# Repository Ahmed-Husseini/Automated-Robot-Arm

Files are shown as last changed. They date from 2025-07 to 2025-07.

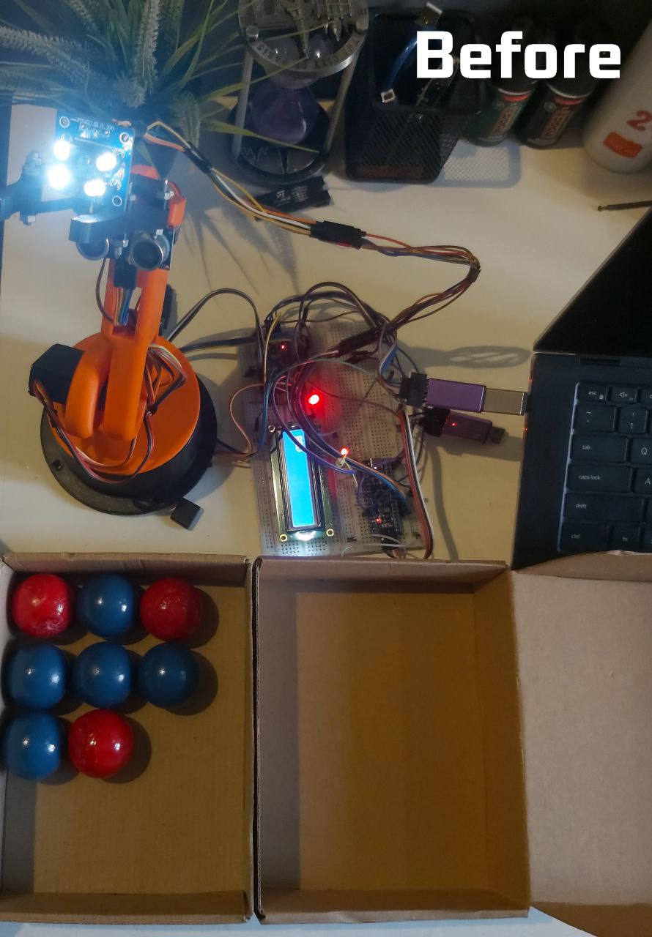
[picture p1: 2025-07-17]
Media/6.jpg

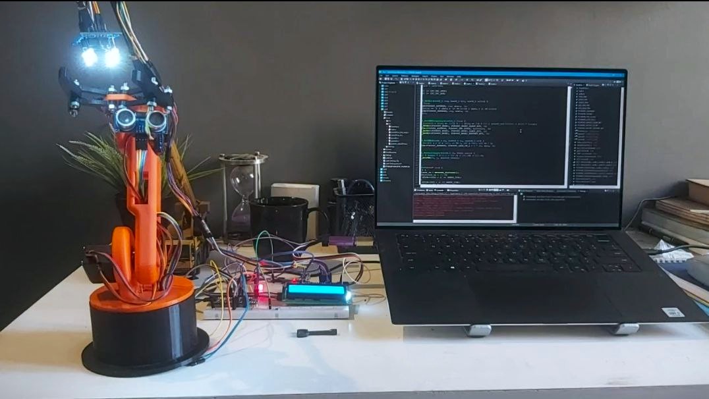
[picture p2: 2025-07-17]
Media/3.jpg

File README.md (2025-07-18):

# Automated-Robot-Arm

An embedded robotic system that classifies and sorts colored objects using a robotic arm controlled by an STM32F103C8T6 microcontroller.

---

## 🎯 Project Overview

The goal of this project is to design, build, and program a robotic arm capable of detecting object color and placing it in the appropriate bin. The robot picks up balls from a central basket, identifies their color using a sensor, and sorts them accordingly.

### 🔄 Operating Logic
1. Arm picks a ball from the central container.
2. A TCS3200 color sensor detects the ball’s color (red or blue).
3. Based on the result:
   - 🔵 Blue → right bin
   - 🔴 Red → left bin
4. The process repeats until the input container is empty.

---

## 🧰 Hardware Components

| Component | Details |
|---|---|
| Microcontroller | STM32F103C8T6 (Blue Pill) |
| Servo Motors | 2× MG966R, 2× SG90 |
| Color Sensor | TCS3200 |
| Ultrasonic Sensor  | HC-SR04 |
| Gyroscope | MPU6050 |
| I2C Servo Driver | PCA9685 |
| LCD (Optional) | I2C 16x2 LCD Display |

---

## 🧠 Software Overview

- **FreeRTOS** used for task scheduling.
- **Register-level programming** (bare-metal) without HAL.
- Key modules:
  - Distance measurement using ultrasonic sensor.
  - Color detection task via TCS3200.
  - Servo control using PCA9685 I2C driver.
- Implemented in C with `CMSIS` and STM32 low-level access.

---

## 📐 Control Design

- DC motor and potentiometer were separated from prebuilt servo loop.
- System modeled and linearized with MATLAB:
  - Moment of Inertia: 0.01 kg·m²
  - Transfer function derived and simulated.
- PID controller designed using MATLAB:
  ```math
  C(s) = 50 + 2s + 100/s

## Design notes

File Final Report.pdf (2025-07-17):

Project Final Report | Mechatronics Engineering MCTR601
Spring 2025

# German University in Cairo

# Mechatronics Engineering (MCTR601)

# Object Classifying Robotic Arm

Name | ID | Lab Number
Ahmed Husseini | 58-21270 | T38
Mohamed Yaser | 58-21125 | T35
Mohamed Mohsen | 58-1653 | T36

## Table of Contents

## 1. Project Description

- Generally explain your project idea and objectives and applications.
- Include a concise overview of what the device does and how it works.
- Mention the main actuators and sensors of the system
- A functional diagram showing all major components and their connections.
- Be sure to label key components in your figures (with concise text and arrows).
Part number | Name
1 Base
2 Arm
3 Gripplers
4 Servo Motors

Overview:
This project involves designing and implementing a simple robotic arm capable of classifying and sorting objects based on their color. The robot picks up randomly placed balls from a central basket and places them into designated places based on their color.

Working Principle:
1. The robotic arm picks up a ball from the central basket.
2. A color detection sensor determines whether the ball is blue or red.
3. Based on the detected color, the arm moves and places the ball into the corresponding basket: Blue ball → Right basket
Red ball → Left basket
4. The process repeats for each ball until the central basket is empty.

Applications:
- Industry and Automation: This project simulates basic industrial product sorting operations in factories.
- Medical Field: Can be used to classify medicines or blood samples in hospitals or pharmacies.
- AI & Machine Learning Integration: Can be expanded by integrating machine learning for improved object recognition.

Actuators: 2x Servo Motors + 2x Micro Servo Motors
Sensors: Ultrasonic (HC-SR04) + Color Sensor (TCS3200) + Gyro (MPU6050) Modules: Servo I2C Driver (PCA9685) + I2C LCD Screen

## Gripplers

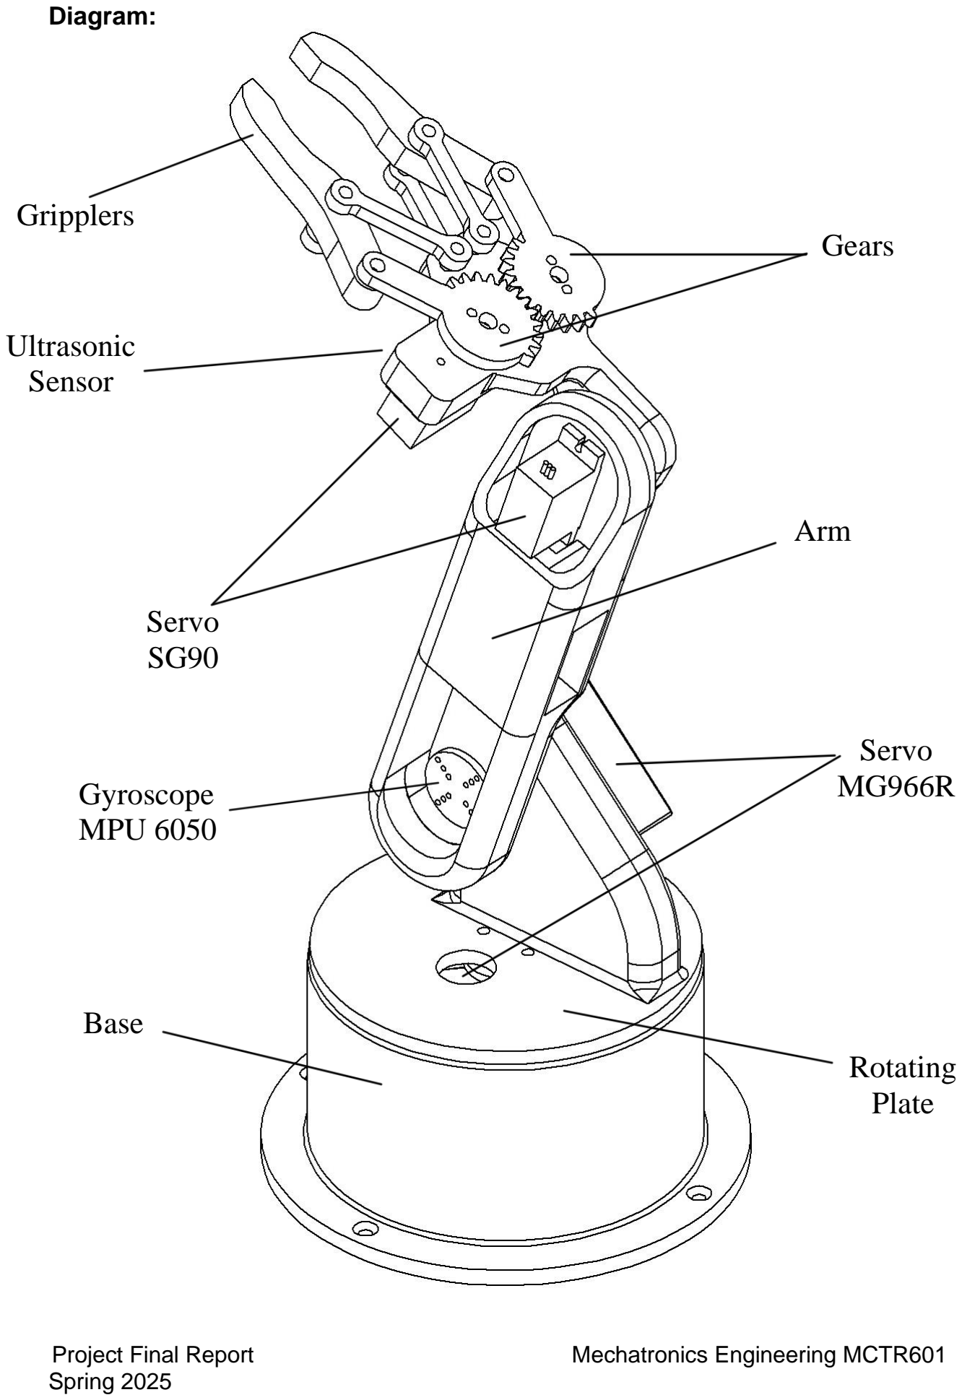
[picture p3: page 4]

Diagram:

## Base

## Arm

## Gears

## Servo MG966R

## Servo

SG90

## Rotating Plate

## Ultrasonic Sensor

## Gyroscope MPU 6050

## 2. Methodology

## 2.1 Mechanical design

Include a detailed description of the system’s mechanical and electromechanical

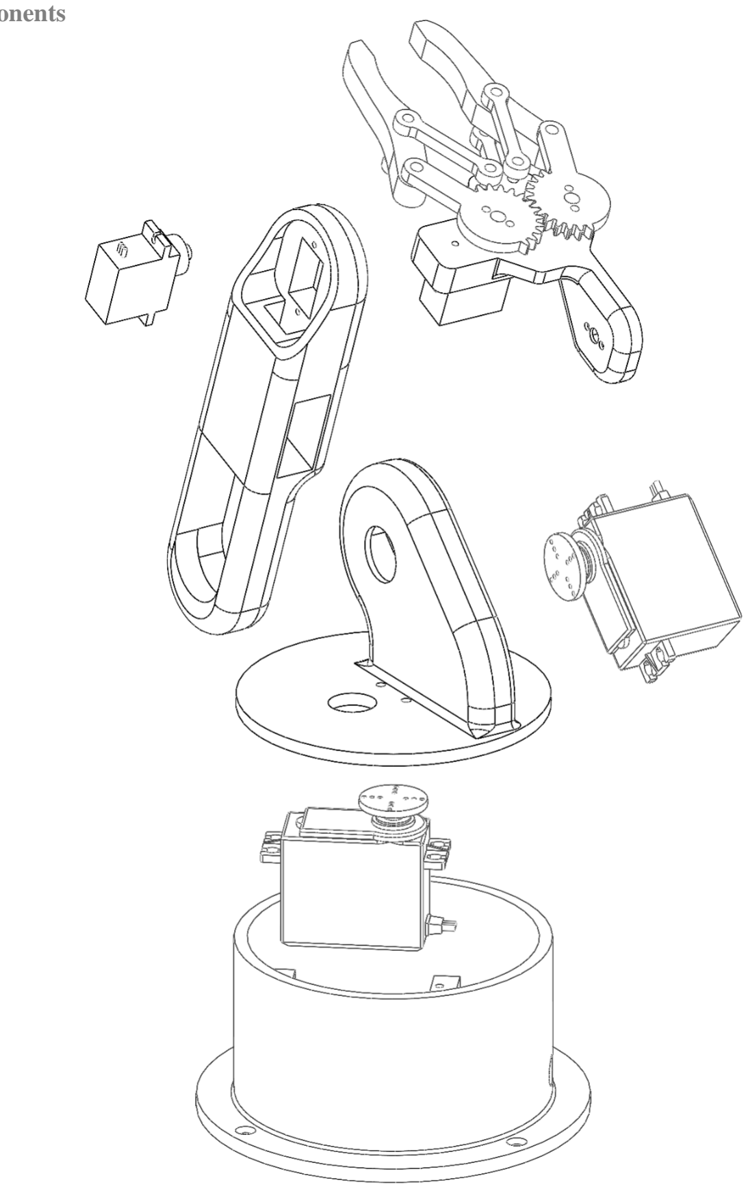
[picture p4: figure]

components

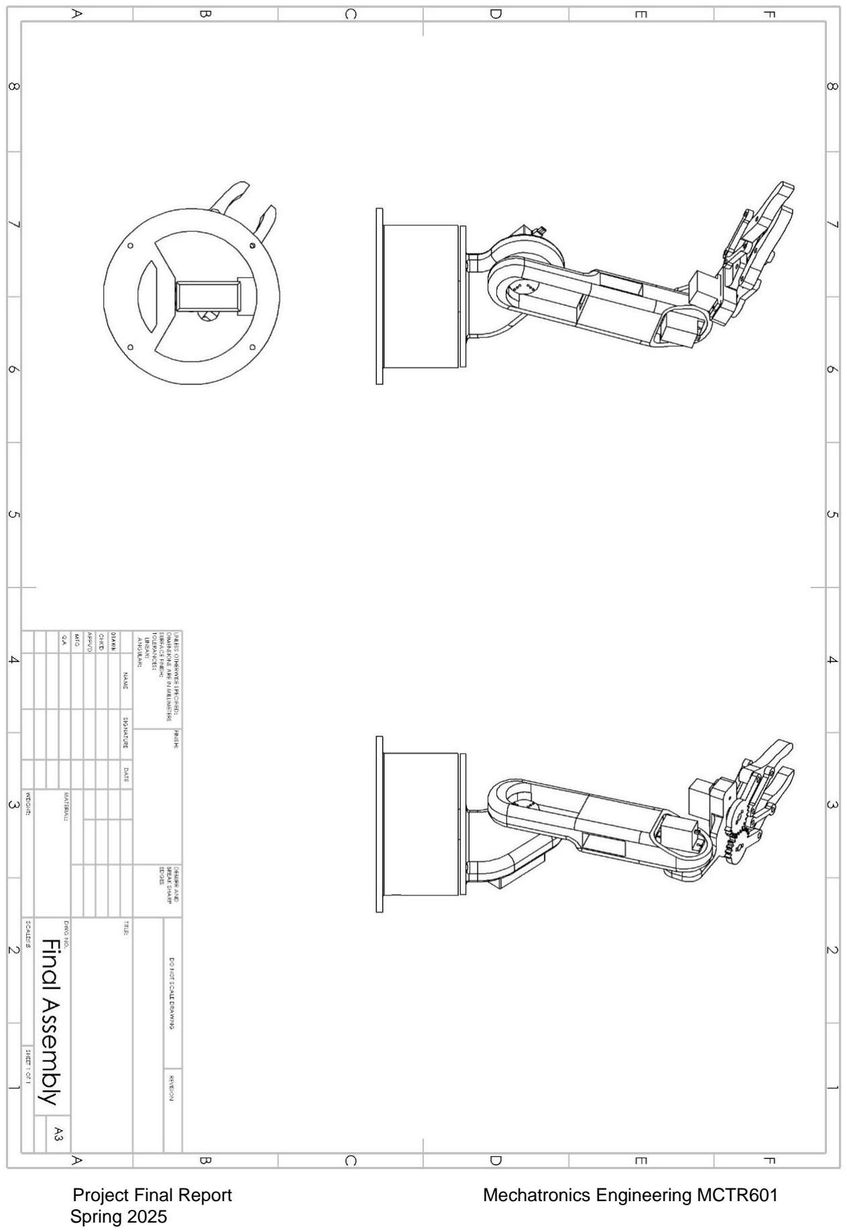
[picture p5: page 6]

## 2.2 Electrical design

Include schematics for the electrical systems showing all connections

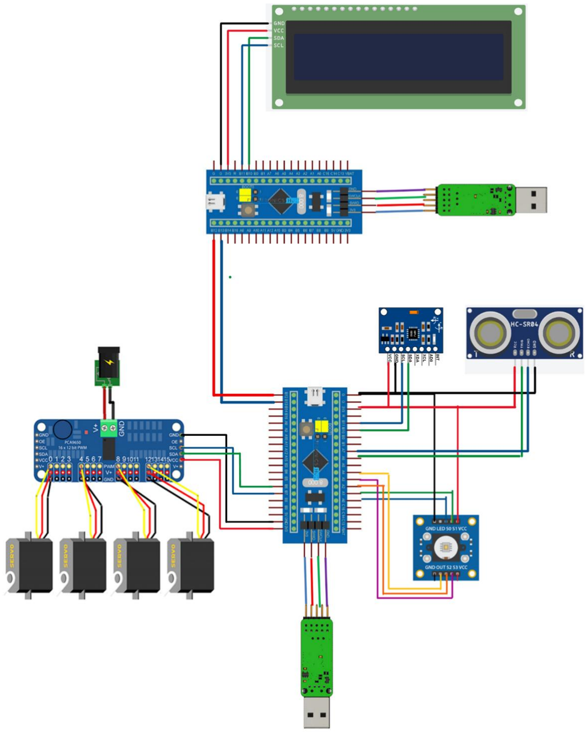
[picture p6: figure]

Control

### 2.3.1. Modeling

This section should show the
- Derivation and linearization of the governing equations
- Derivation of the Transfer function model of the system
- Block Diagram representation

The controlled variable in this project is the motor’s angular position. And since Servo motors already come with a closed-loop control, we hacked it and used the DC motor and the potentiometer individually.

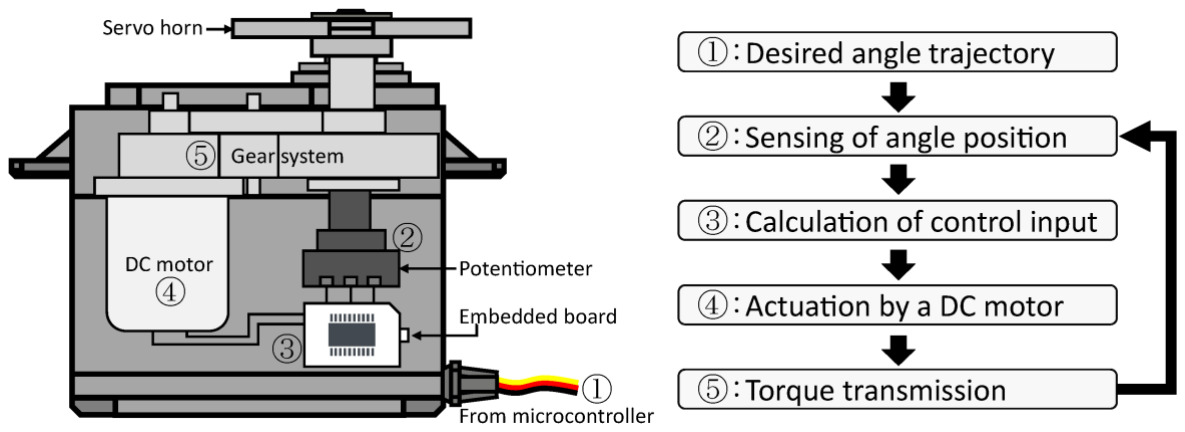
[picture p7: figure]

After simulating the mechanical model of the arm Solidworks, we found that:

### Moment of Inertia (J) = 0.01 kg. m² Damping Coefficient (b) = 0.001 N. m. s

And, from the motor’s datasheet:

### Motor Constant (K) = 0.05 N. m/A Armature Resistance (R) = 2 Ω Armature Inductance (L) = 0.005 H

a) The mathematical model of the DC motor system:

### vi − iR − L

di
dt − Keθ̇m = 0 | (1)
Jmθ̈m = T − Bθ̇m | ⇒ | Jmθ̈m + Bθ̇m = KTi | (2)

### JLθ̈=

1
n
T | ⇒ | JLθ̈=
| | 1 n
| | KTi | (3)

b) Obtaining transfer function:

Using Laplace Transform:

### Eq1: Vi

### (s) − RI(s) − LsI(s) − KesΘm(s) = 0

Vi

(s) = (R + Ls) I(s) + KesΘm(s) | (1)

### Eq2: Jms

### 2Θm(s) + BsΘm(s) = KTI(s)

### Θm(s) =

KT

### Jms

2 + Bs I(s) | (2)

### Eq3: JLs

2Θ(s) −

1
n

### KTI(s) = 0

I(s) =

### nJLs

2
KT
Θ(s) | (3)

from (2) and (3) we get : Θm(s) =

KT
Jms

2+Bs

×

nJLs

2

KT

Θ(s) =

nJLs

2

Jms

2+Bs

Θ(s) | (4)

substituting with (3) and (4) in (1) :

Vi

### (s) = (R + Ls)

### nJLs

2
KT

### Θ(s) + Kes

### nJLs

2

### Jms

### 2 + Bs Θ(s)

Vi

(s) = (

### RnJLs

### 2 + LnJLs

3
KT

+

### KenJLs

3

### Jms

### 2 + Bs)Θ(s)

Vi

(s) =

### nJLs((Jms + B)(Ls + R) + KTKe) JmKT

Θ(s)

Θ(s)
Vi

(s)

=

Jm

### nJL

KT

### s((Jms + B)(Ls + R) + KTKe)

### Transfer Function =

0. 01
10
0. 05

### s((0. 01 s + 0. 001)(0. 005 s + 2) + 0. 05)

c) Simulink Block diagram

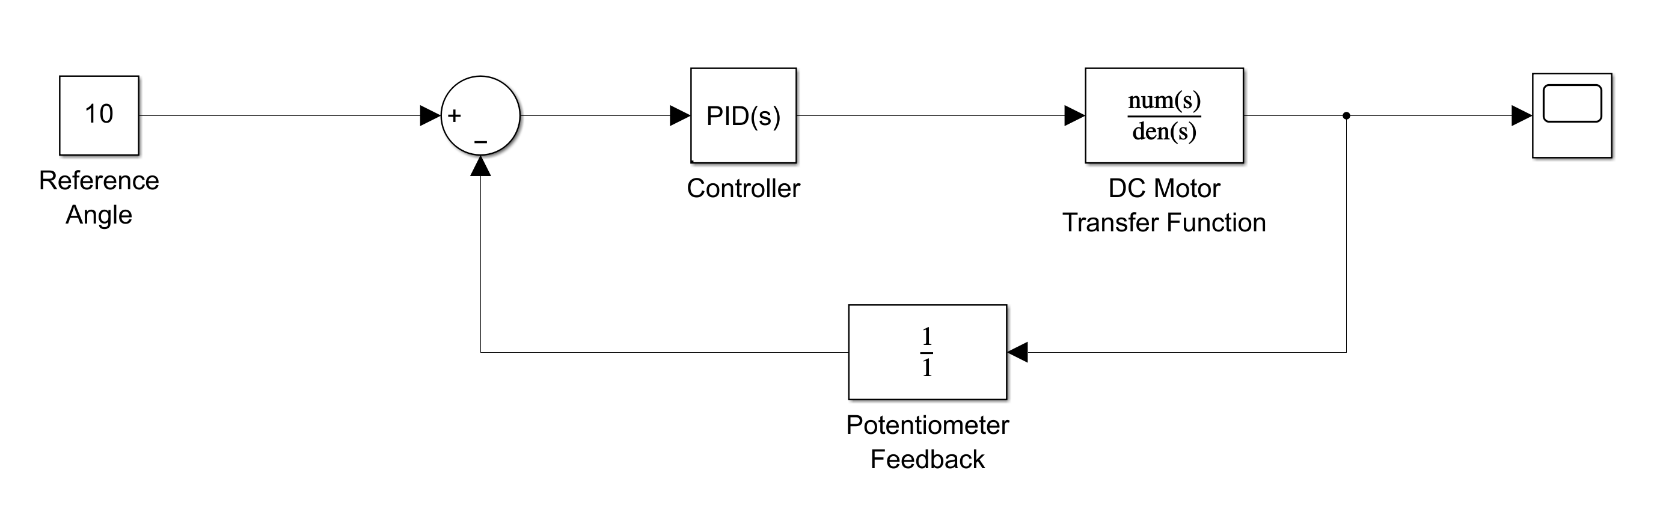
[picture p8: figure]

### 2.3.2. Analysis

- Solve equations and get the open loop response

Step response h(t) = L

−1

{H(s) ∗

1
s

}

H(s) =

### JmKT nJL

1

### s((Jms + B)(Ls + R) + KTKe)

∗

1
s

H(s) =

0.01
10

0.05
s

2((0.01 s + 0.001)(0.005 s + 2) + 0.05)

H(s) =

0.0005
s

2(0.005 s

2 + 2.0005 s + 0.25)

H(s) =

6.188 × 10⁻⁵
s

+

6.188 × 10⁻⁵
s + 3.125 +

6.188 × 10⁻⁵
s + 1374.38

## ℎ(t) = 6.188 × 10⁻⁵ − 6.188 × 10⁻⁵e

## −3.125t − 6.188 × 10⁻⁵e

−1374.38t

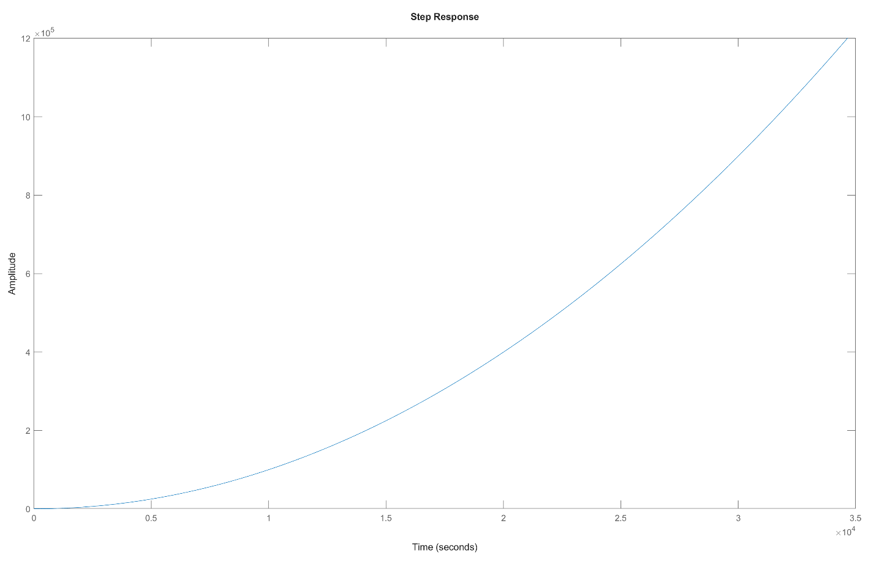
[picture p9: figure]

### 2.3.3. Controller Design

- Show the controller design steps
- Clearly show the control law
- Show the closed loop simulations

Hint: You may use MATLAB’s SISO tool for the simulations in the analysis and design stages

Step 1: Define the Plant in MATLAB
Step 2: Analyze Open-Loop System

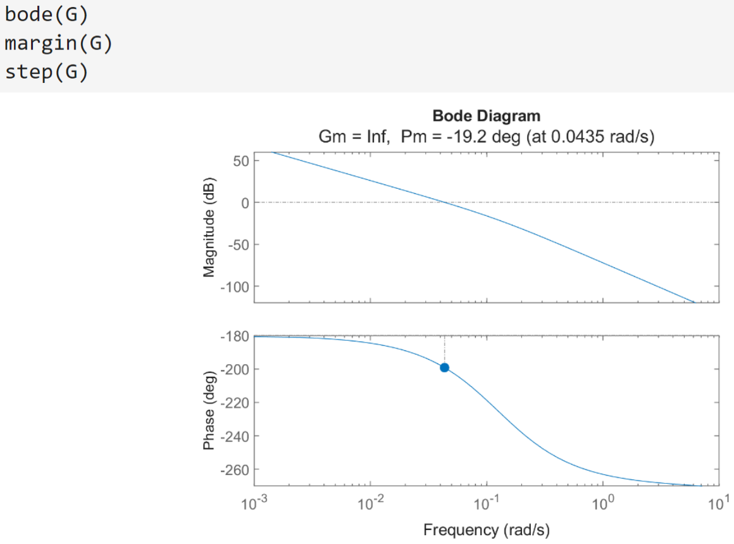
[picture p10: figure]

Step 3: Design PID Controller Using pidtune Function

### C = Kp + Kds +

Ki
s

= 50 + 2 s +

100
s

=

50 s + 2 s

2 + 100
s

Step 4: Form the Closed-Loop System
Step 5: Analyze Closed-Loop Response

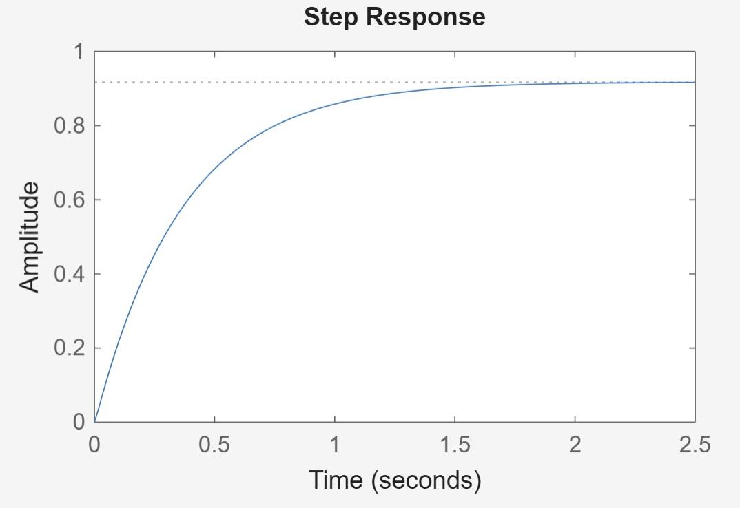
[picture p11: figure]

## 2.3 Programming

Include the used codes and a concise software flowchart

#include "stm32f103xb.h"

#include "FreeRTOS.h"

#include "task.h"

#include <stdio.h>

// ==== PIN DEFINITIONS ====

// Ultrasonic

#define TRIG_PIN | 6 | // PA6

#define ECHO_PIN | 7 | // PA7

#define DEBUG_PIN | 14 // PB14

// Color sensor

#define LED_RED_PIN 12 // PB12 #define LED_BLUE_PIN 13 // PB13

// PCA9685

#define PCA9685_ADDRESS | 0x80

#define PCA9685_MODE1 | 0x00

#define PCA9685_PRE_SCALE | 0xFE

#define PCA9685_LED0_ON_L | 0x06

#define PCA9685_MODE1_SLEEP_BIT 4 #define PCA9685_MODE1_AI_BIT 5 #define PCA9685_MODE1_RESTART_BIT 7

// ==== GLOBAL VARIABLES ====

volatile float distance_cm = 0;
volatile uint16_t capture1 = 0, capture2 = 0; volatile uint8_t captured = 0;

// ==== UTILS ====

void delay_us(uint16_t us) { TIM1->CNT = 0;
while (TIM1->CNT < us);
}

void delayMs(uint32_t ms) { vTaskDelay(pdMS_TO_TICKS(ms)); }

// ==== CLOCK CONFIG ====

void sys_clock_config(void) {
RCC->CR |= RCC_CR_HSEON;
while (!(RCC->CR & RCC_CR_HSERDY));
RCC->CFGR |= RCC_CFGR_PLLSRC | RCC_CFGR_PLLMULL9;
RCC->CR |= RCC_CR_PLLON;
while (!(RCC->CR & RCC_CR_PLLRDY));
FLASH->ACR |= FLASH_ACR_LATENCY_2;
RCC->CFGR |= RCC_CFGR_SW_PLL;
while (!(RCC->CFGR & RCC_CFGR_SWS_PLL)); SystemCoreClockUpdate();
}

// ==== GPIO INIT ====

void gpio_init(void) {
RCC->APB2ENR |= RCC_APB2ENR_IOPAEN | RCC_APB2ENR_IOPBEN |
RCC->APB2ENR |= RCC_APB2ENR_AFIOEN;

// PA6 – TRIG
GPIOA->CRL &= ~(0xF << (4 * TRIG_PIN)); GPIOA->CRL |= (0x1 << (4 * TRIG_PIN));

// PA7 – ECHO
GPIOA->CRL &= ~(0xF << (4 * ECHO_PIN)); GPIOA->CRL |= (0x4 << (4 * ECHO_PIN));

// PB14 - Debug LED
GPIOB->CRH &= ~(0xF << (4 * (DEBUG_PIN - 8))); GPIOB->CRH |= (0x1 << (4 * (DEBUG_PIN - 8)));

// PA0 - TCS3200 OUT (input floating)
GPIOA->CRL &= ~(GPIO_CRL_MODE0 | GPIO_CRL_CNF0);
GPIOA->CRL |= GPIO_CRL_CNF0_0;

// PA1–PA4 - S0–S3 (outputs)
GPIOA->CRL |= (GPIO_CRL_MODE1_1 | GPIO_CRL_MODE2_1 |
GPIO_CRL_MODE3_1 | GPIO_CRL_MODE4_1);

// PB12, PB13 – LEDs
GPIOB->CRH &= ~(GPIO_CRH_MODE12 | GPIO_CRH_CNF12 |
GPIO_CRH_MODE13 | GPIO_CRH_CNF13);
GPIOB->CRH |= (GPIO_CRH_MODE12_1 | GPIO_CRH_MODE13_1);

// PB6, PB7 - I2C1 (alt function open-drain)
GPIOB->CRL &= ~(GPIO_CRL_MODE6 | GPIO_CRL_CNF6 |
GPIO_CRL_MODE7 | GPIO_CRL_CNF7);
GPIOB->CRL |= (GPIO_CRL_MODE6_1 | GPIO_CRL_CNF6_1 | GPIO_CRL_CNF6_0);
GPIOB->CRL |= (GPIO_CRL_MODE7_1 | GPIO_CRL_CNF7_1 | GPIO_CRL_CNF7_0);
}

// ==== TIM CONFIG ====

void TIM1_us_init(void) {
RCC->APB2ENR |= RCC_APB2ENR_TIM1EN; TIM1->PSC = (SystemCoreClock / 1000000) - 1; TIM1->ARR = 0xFFFF;
TIM1->CR1 |= TIM_CR1_CEN;
}

void TIM2_InputCapture_Config(void) { RCC->APB1ENR |= RCC_APB1ENR_TIM2EN; TIM2->PSC = 71;
TIM2->ARR = 0xFFFF;
TIM2->CCMR1 = 0x01;
TIM2->CCER = TIM_CCER_CC1E; TIM2->DIER |= TIM_DIER_CC1IE; TIM2->CR1 |= TIM_CR1_CEN;
NVIC_EnableIRQ(TIM2_IRQn); }

// ==== INTERRUPTS ====

void TIM2_IRQHandler(void) {
if (TIM2->SR & TIM_SR_CC1IF) {
if (!captured) capture1 = TIM2->CCR1, captured = 1; else capture2 = TIM2->CCR1, captured = 2;
TIM2->SR &= ~TIM_SR_CC1IF;
}
}

// ==== ULTRASONIC ====

float measure_distance(void) { GPIOA->BSRR = (1 << TRIG_PIN); delay_us(10);
GPIOA->BRR = (1 << TRIG_PIN);

while (!(GPIOA->IDR & (1 << ECHO_PIN))); uint32_t start = TIM1->CNT;
while (GPIOA->IDR & (1 << ECHO_PIN));
uint32_t end = TIM1->CNT;

uint32_t diff = (end >= start) ? (end - start) : (0xFFFF - start + end); return (diff * 0.0343f) / 2.0f;
}

// ==== TCS3200 COLOR SENSOR ====

void set_color_filter(uint8_t s2, uint8_t s3) {
if (s2) GPIOA->BSRR = GPIO_BSRR_BS3; else GPIOA->BSRR = GPIO_BSRR_BR3; if (s3) GPIOA->BSRR = GPIO_BSRR_BS4; else GPIOA->BSRR = GPIO_BSRR_BR4; }

uint32_t measure_frequency(void) {
captured = 0;
while (captured < 2);
uint16_t period_ticks = (capture2 > capture1) ? (capture2 - capture1) : (0xFFFF - capture1 + capture2);
return (1000000UL / period_ticks);
}

// ==== I2C & PCA9685 ====

void I2C1_Init(void) {
RCC->APB1ENR |= RCC_APB1ENR_I2C1EN; I2C1->CR1 &= ~I2C_CR1_PE;
I2C1->CR2 = 36;
I2C1->CCR = 180;
I2C1->TRISE = 37;
I2C1->CR1 |= I2C_CR1_PE;
}

void I2C1_Write(uint8_t devAddr, uint8_t regAddr, uint8_t *data, uint8_t len){ while (I2C1->SR2 & I2C_SR2_BUSY);
I2C1->CR1 |= I2C_CR1_START;
while (!(I2C1->SR1 & I2C_SR1_SB)); (void)I2C1->SR1;
I2C1->DR = devAddr;
while (!(I2C1->SR1 & I2C_SR1_ADDR)); (void)I2C1->SR2; I2C1->DR = regAddr;
while (!(I2C1->SR1 & I2C_SR1_TXE));

for (uint8_t i = 0; i < len; i++) {
I2C1->DR = data[i];
while (!(I2C1->SR1 & I2C_SR1_TXE)); }
I2C1->CR1 |= I2C_CR1_STOP;
}

void I2C1_Read(uint8_t devAddr, uint8_t regAddr, uint8_t *data, uint8_t len) { while (I2C1->SR2 & I2C_SR2_BUSY);
I2C1->CR1 |= I2C_CR1_START;
while (!(I2C1->SR1 & I2C_SR1_SB)); (void)I2C1->SR1;
I2C1->DR = devAddr;
while (!(I2C1->SR1 & I2C_SR1_ADDR)); (void)I2C1->SR2; I2C1->DR = regAddr;
while (!(I2C1->SR1 & I2C_SR1_TXE));
I2C1->CR1 |= I2C_CR1_START;
while (!(I2C1->SR1 & I2C_SR1_SB)); (void)I2C1->SR1;
I2C1->DR = devAddr | 0x01;
while (!(I2C1->SR1 & I2C_SR1_ADDR)); (void)I2C1->SR2; for (uint8_t i = 0; i < len; i++) {
if (i == len - 1) I2C1->CR1 &= ~I2C_CR1_ACK; while (!(I2C1->SR1 & I2C_SR1_RXNE));
data[i] = I2C1->DR;
}
I2C1->CR1 |= I2C_CR1_STOP;
I2C1->CR1 |= I2C_CR1_ACK;
}

void PCA9685_SetBit(uint8_t reg, uint8_t bit, uint8_t value) { uint8_t data;
I2C1_Read(PCA9685_ADDRESS, reg, &data, 1);
data = (value == 0) ? (data & ~(1 << bit)) : (data | (1 << bit));
I2C1_Write(PCA9685_ADDRESS, reg, &data, 1);
delayMs(1);
}

void PCA9685_SetPWMFrequency(uint16_t freq) {
uint8_t prescale = (freq >= 1526) ? 3 : (freq <= 24) ? 255 : (uint8_t)(25000000 / (4096 * freq)); PCA9685_SetBit(PCA9685_MODE1, PCA9685_MODE1_SLEEP_BIT, 1); I2C1_Write(PCA9685_ADDRESS, PCA9685_PRE_SCALE, &prescale, 1); PCA9685_SetBit(PCA9685_MODE1, PCA9685_MODE1_SLEEP_BIT, 0); PCA9685_SetBit(PCA9685_MODE1, PCA9685_MODE1_RESTART_BIT, 1); }

void PCA9685_SetPWM(uint8_t ch, uint16_t on, uint16_t off) { uint8_t data[4] = { on & 0xFF, on >> 8, off & 0xFF, off >> 8 }; I2C1_Write(PCA9685_ADDRESS, PCA9685_LED0_ON_L + 4 * ch, data, 4); }

void PCA9685_SetServoAngle(uint8_t ch, float angle) {
float val = (angle * (511.9 - 102.4) / 180.0f) + 102.4f; PCA9685_SetPWM(ch, 0, (uint16_t)val);
}

// ==== TASKS ====

void SensorTask(void* arg) { while (1) {
distance_cm = measure_distance(); if (distance_cm < 10.0f)
GPIOB->BSRR = (1 << DEBUG_PIN); else
GPIOB->BRR = (1 << DEBUG_PIN); vTaskDelay(pdMS_TO_TICKS(200)); }
}

void vColorTask(void *pv) { uint32_t freq_r, freq_b;

while (1) {

// Red

set_color_filter(0, 0); // S2=0, S3=0 => Red vTaskDelay(pdMS_TO_TICKS(100));
freq_r = measure_frequency();

// Blue

set_color_filter(0, 1); // S2=0, S3=1 => Blue vTaskDelay(pdMS_TO_TICKS(100));
freq_b = measure_frequency();

// Determine dominant color and light LEDs

if (freq_r > freq_b) {
GPIOB->BSRR = GPIO_BSRR_BS12; | // Red LED ON
GPIOB->BSRR = GPIO_BSRR_BR13; | // Blue LED OFF
} else if (freq_b > freq_r) {
GPIOB->BSRR = GPIO_BSRR_BS13; | // Blue LED ON
GPIOB->BSRR = GPIO_BSRR_BR12; | // Red LED OFF
} else {
GPIOB->BSRR = GPIO_BSRR_BR12 | GPIO_BSRR_BR13; // Both OFF
}

vTaskDelay(pdMS_TO_TICKS(300));
}
}

void vServoTask(void *pv) {
I2C1_Init(); PCA9685_SetPWMFrequency(50); PCA9685_SetBit(PCA9685_MODE1, PCA9685_MODE1_AI_BIT, 1); while (1) {
PCA9685_SetServoAngle(0, 90); PCA9685_SetServoAngle(1, 30); PCA9685_SetServoAngle(2, 120); delayMs(1000);
PCA9685_SetServoAngle(3, 180); delayMs(1000);

PCA9685_SetServoAngle(1, 130); PCA9685_SetServoAngle(2, 90); delayMs(1000);
while ((GPIOB->IDR & GPIO_IDR_IDR14)==0); PCA9685_SetServoAngle(3, 30);
delayMs(1000);

PCA9685_SetServoAngle(1, 30); // Color Measuring Position delayMs(3000);

while(((GPIOB->IDR & GPIO_IDR_IDR12)==0)
& ((GPIOB->IDR & GPIO_IDR_IDR13)==0));

if (GPIOB->IDR & GPIO_IDR_IDR12) { PCA9685_SetServoAngle(0, 180);
} else {
PCA9685_SetServoAngle(0, 0);
}

PCA9685_SetServoAngle(1, 100); PCA9685_SetServoAngle(2, 90); delayMs(1000);
PCA9685_SetServoAngle(3, 180); delayMs(1000);
}
}

// ==== MAIN ====

int main(void) {
sys_clock_config();
gpio_init();
TIM1_us_init();
TIM2_InputCapture_Config();
GPIOA->BSRR = GPIO_BSRR_BS1 | GPIO_BSRR_BS2; // S0, S1 = 1

xTaskCreate(SensorTask, "Sensor", 128, NULL, 2, NULL); xTaskCreate(vColorTask, "Color", 256, NULL, 1, NULL); xTaskCreate(vServoTask, "Servo", 256, NULL, 1, NULL); vTaskStartScheduler();

while (1);
}

## 3. Design Evaluation

Briefly describe the success of the hardware by comparing the experimental results to the model simulations.
Comment on the obtained results of the system performance and the graphs.

Mechanical

In the Mechanical part, everything worked perfectly as designed. The robot members were able to bare the stress as calculated in the stress analysis part. All the motors generated enough torque to move and rotate their respective member.

Electrical

In the Electrical part, the performance was satisfying.

## 4. Appendix

Append detailed wiring diagrams (if details are not included in earlier figures), anything else supporting the system details section.

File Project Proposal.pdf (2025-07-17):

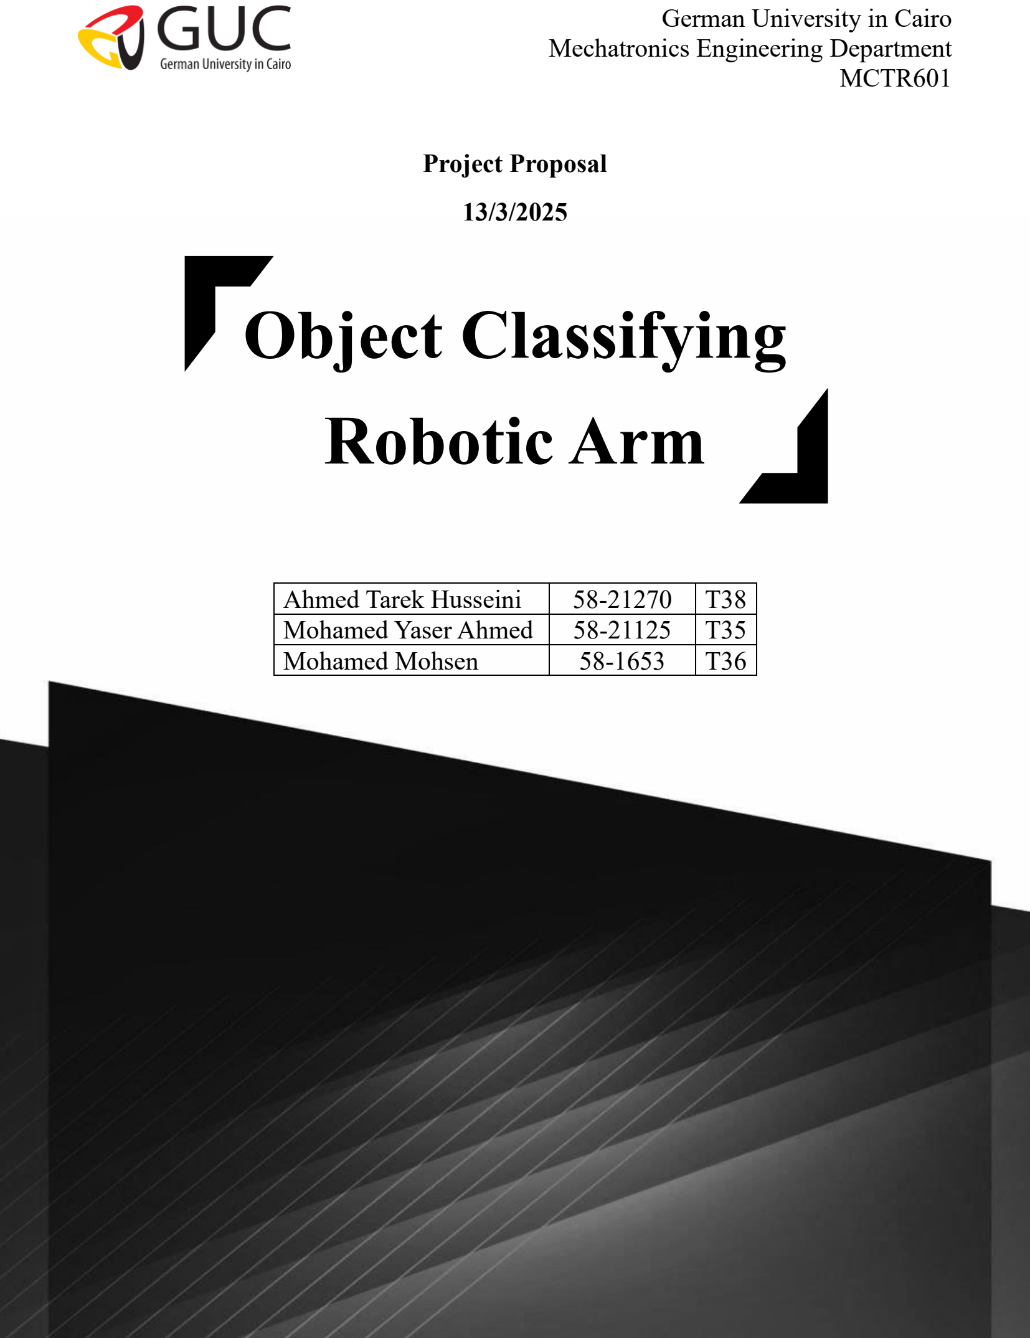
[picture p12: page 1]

German University in Cairo Mechatronics Engineering Department MCTR601

Project Proposal

13/3/2025

# Object Classifying

# Robotic Arm

Ahmed Tarek Husseini | 58-21270 | T38
Mohamed Yaser Ahmed | 58-21125 | T35
Mohamed Mohsen | 58-1653 | T36

## Overview:

This project involves designing and implementing a simple robotic arm capable of classifying and sorting objects based on their color. The robot picks up randomly placed balls from a central basket and places them into designated bins based on their color.

Working Principle

1. The robotic arm picks up a ball from the central basket.
2. A color detection sensor determines whether the ball is blue or red.
3. Based on the detected color, the arm moves and places the ball into the corresponding basket:
- Blue ball → Right basket
- Red ball → Left basket
4. The process repeats for each ball until the central basket is empty.

Applications

- Automation and Sorting Systems: This project simulates basic industrial sorting applications.
- AI & Machine Learning Integration: Can be expanded by integrating machine learning for improved object recognition.
- STEM Education: Provides a hands-on experience in robotics, sensors, and automation.

1

## Components List:

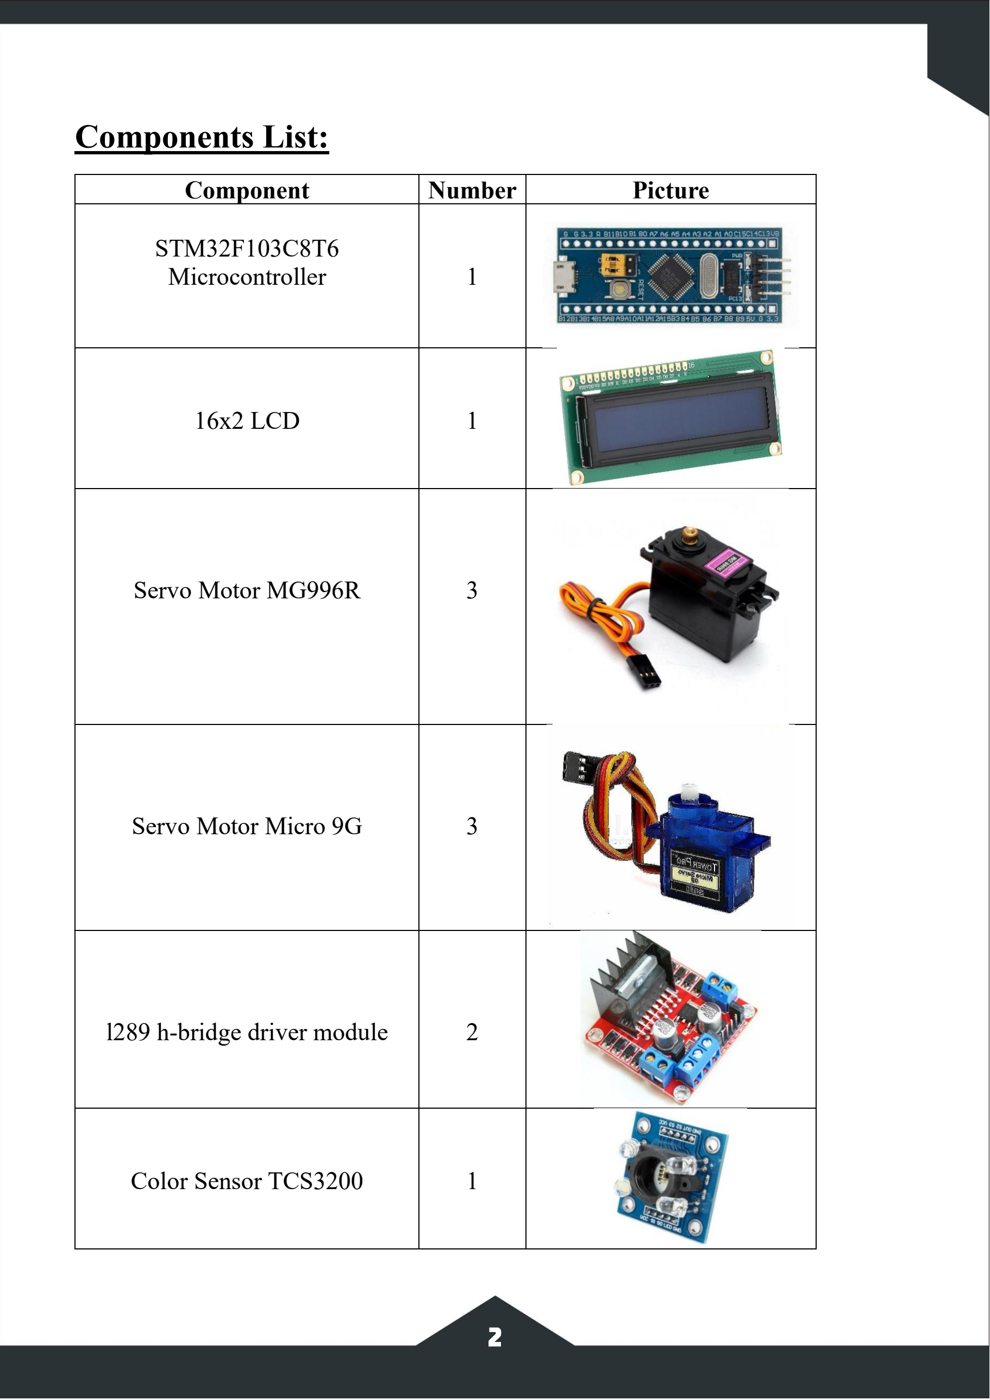
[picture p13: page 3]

Component | Number | Picture
STM32F103C8T6 Microcontroller | 1
16x2 LCD | 1
Servo Motor MG996R | 3
Servo Motor Micro 9G | 3
l289 h-bridge driver module | 2
Color Sensor TCS3200 | 1 2

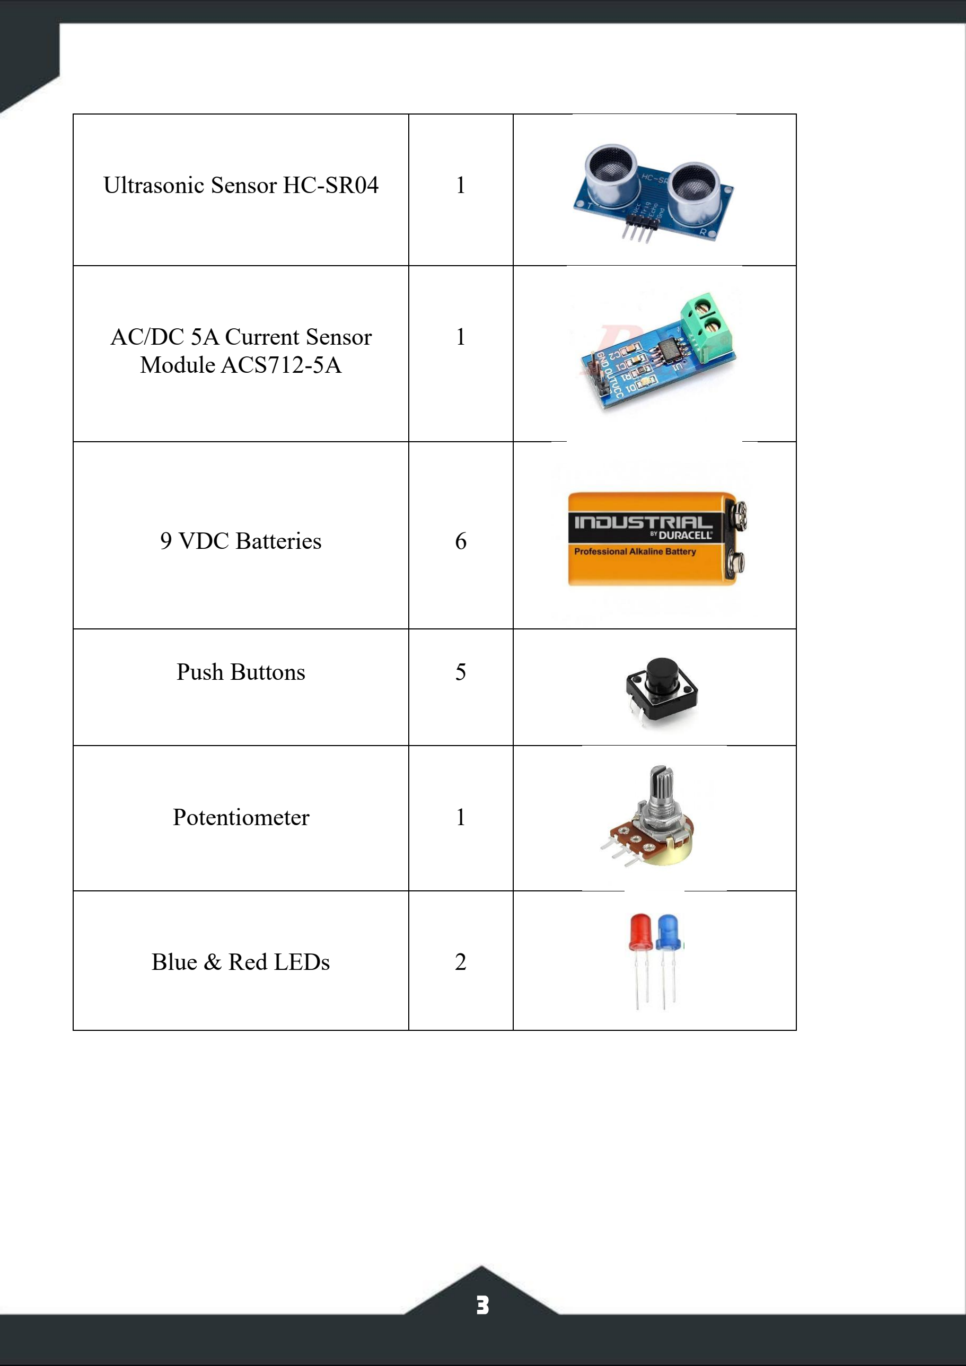
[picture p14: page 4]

Ultrasonic Sensor HC-SR04 | 1
AC/DC 5A Current Sensor Module ACS712-5A | 1
9 VDC Batteries | 6
Push Buttons | 5
Potentiometer | 1
Blue & Red LEDs | 2

3

## Motors Distribution:

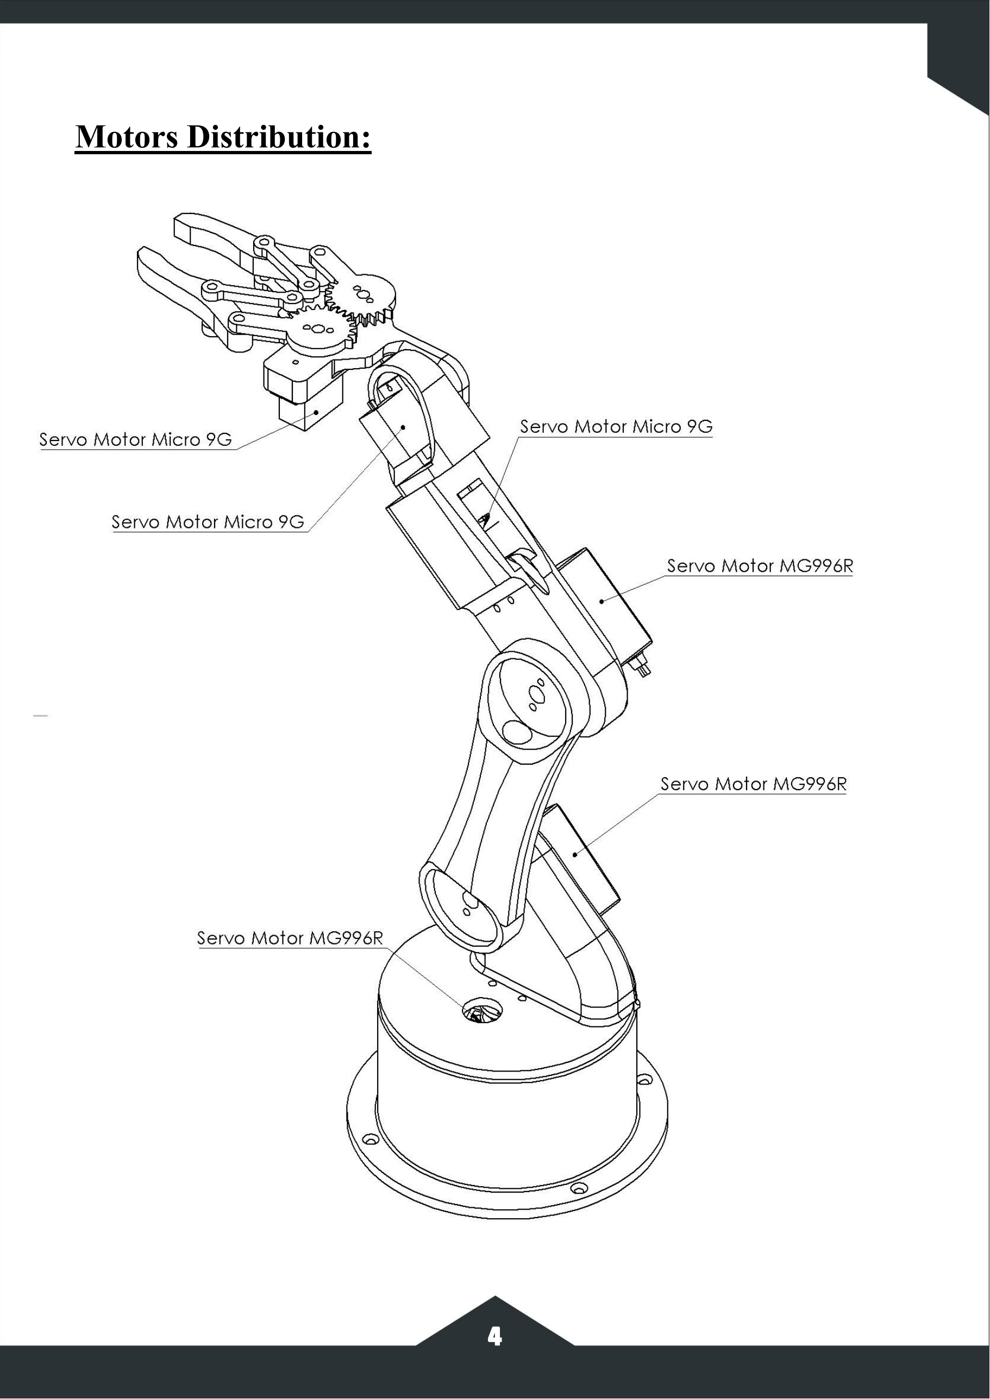
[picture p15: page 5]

4

## Dynamic Model:

The DC servomotor transfer function block diagram can be created through an examination of the armature current equation. Ohm’s law for impedances is used to write the armature current equation in the s-domain. Note that the equation includes both real and imaginary parts of the impedance. The reactance is inductive.

Ia =

Va − Vb
Ra + s ∗ La

= (

1
Ra + s ∗ La

) ∗ (Va − Vb
) = GI ∗ (Va − Vb)

The block diagram model of this equation:

Similarly, the equations of motion can be used to relate the armature current to torque, torque to angular displacement, and angular displacement to the back-emf.

The complete block diagram:

5

Note that this actuator is a feedback system that can be reduced to the standard form for derivation of the gain. The series gain path is reduced to an equivalent gain through multiplication. The reduced block diagram is shown in the following figure. The forward path gain is traditionally called G while the feedback path gain is H.

The gain can be calculated directly from the reduced block diagram:

TF =

θm
Vm

=

G
1 + GH =

GI ∗ Kt ∗ Gθ
1 + (GI ∗ Kt ∗ Gθ)(Kb ∗ s)

Note that the denominator contains a + sign because the block diagram has negative feedback at the summation node. The denominator would contain a - sign if the block diagram used positive feedback.

6

## Color Detection System:

The TCS3200 color sensor converts the light intensity from the RGB color filters into a frequency output. We can model the sensor's output as follows:

- The TCS3200 outputs a frequency proportional to the intensity of the color
detected. The higher the intensity of a | specific
color (e.g., red or blue), the higher the
frequency.

We can model the color sensor's output frequency fcolor(t) based on the intensity of the color:

fcolor(t) = Kcolor. Icolor(t)

Where:

- fcolor(t) = Frequency output of the TCS3200 sensor.
- Kcolor = Calibration constant for the specific color
- Icolor(t) = Light intensity of the color detected (which corresponds to the ball's color).

For color detection:

- If fcolor > Tℎresℎoldblue, classify as blue.
- If fcolor > Tℎresℎoldred, classify as Red.

This means the system classifies the ball based on the frequency of the sensor output and compares it to predefined thresholds to decide which color is detected.

7

## Ultrasonic Sensor:

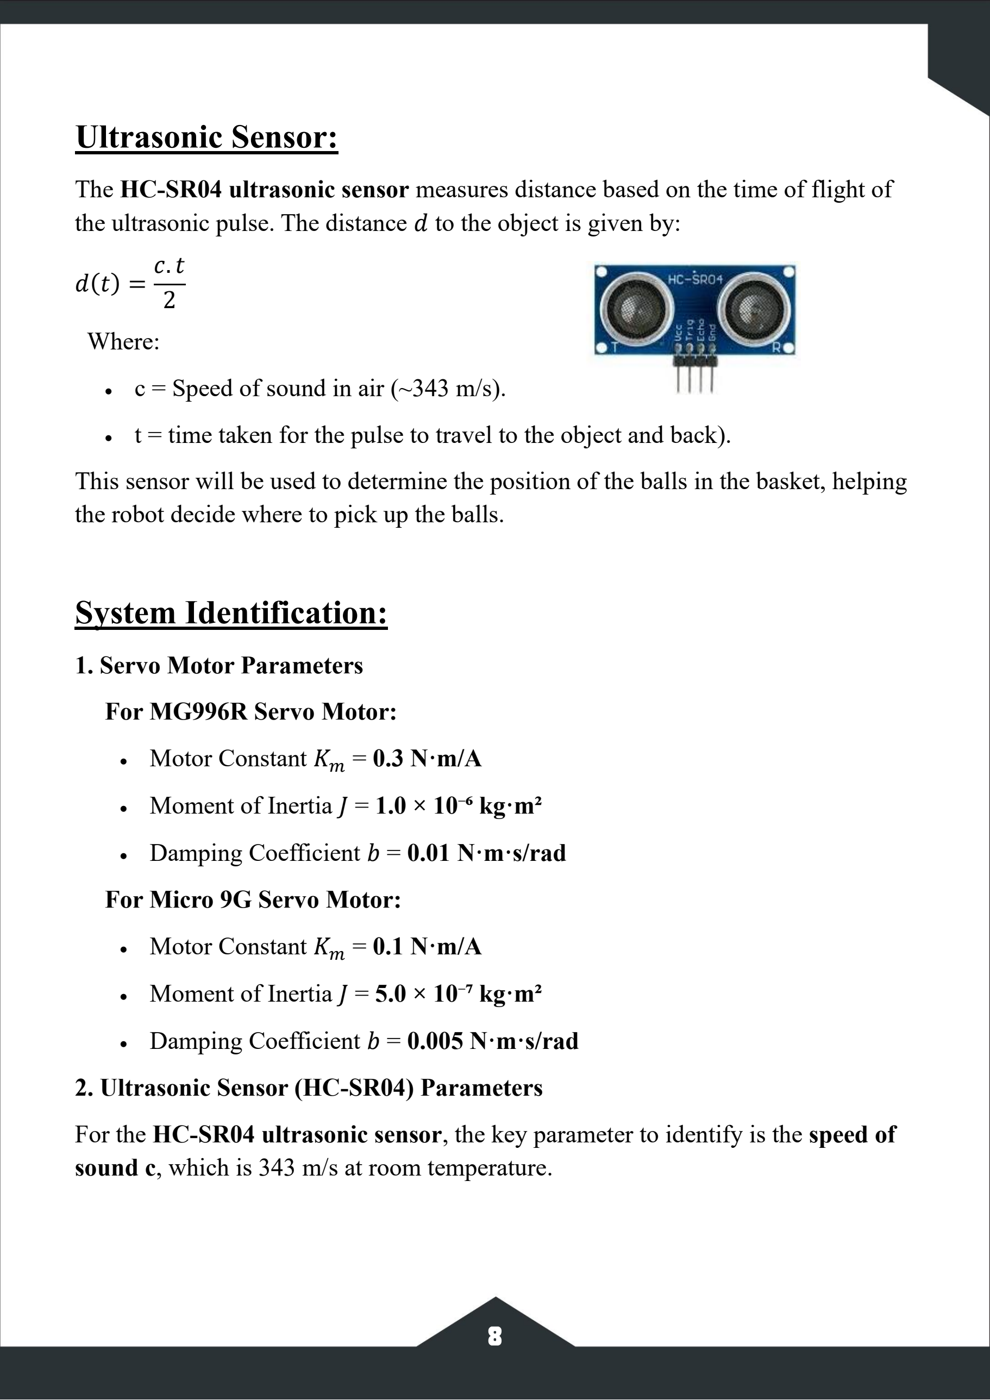
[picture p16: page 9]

The HC-SR04 ultrasonic sensor measures distance based on the time of flight of the ultrasonic pulse. The distance d to the object is given by:

d(t) =

c.t
2

Where:

- c = Speed of sound in air (~343 m/s).
- t = time taken for the pulse to travel to the object and back).

This sensor will be used to determine the position of the balls in the basket, helping the robot decide where to pick up the balls.

## System Identification:

### 1. Servo Motor Parameters

For MG996R Servo Motor:

- Motor Constant Km = 0.3 N·m/A
- Moment of Inertia J = 1.0 × 10⁻⁶ kg·m²
- Damping Coefficient b = 0.01 N·m·s/rad

For Micro 9G Servo Motor:

- Motor Constant Km = 0.1 N·m/A
- Moment of Inertia J = 5.0 × 10⁻⁷ kg·m²
- Damping Coefficient b = 0.005 N·m·s/rad

### 2. Ultrasonic Sensor (HC-SR04) Parameters

For the HC-SR04 ultrasonic sensor, the key parameter to identify is the speed of sound c, which is 343 m/s at room temperature.

8

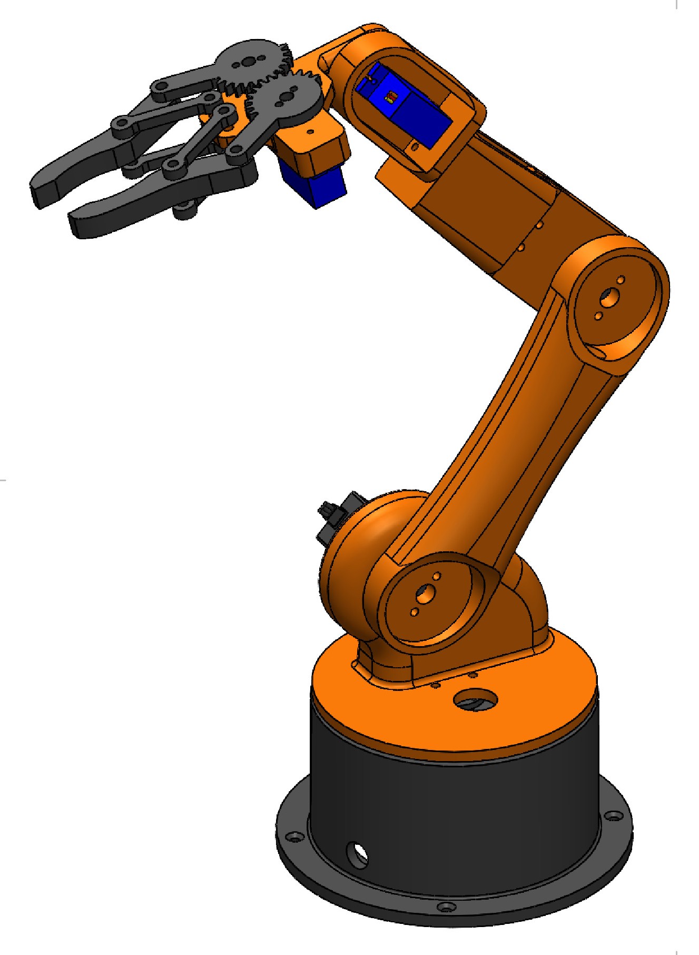
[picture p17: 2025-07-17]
Model/Images/Colored.JPG

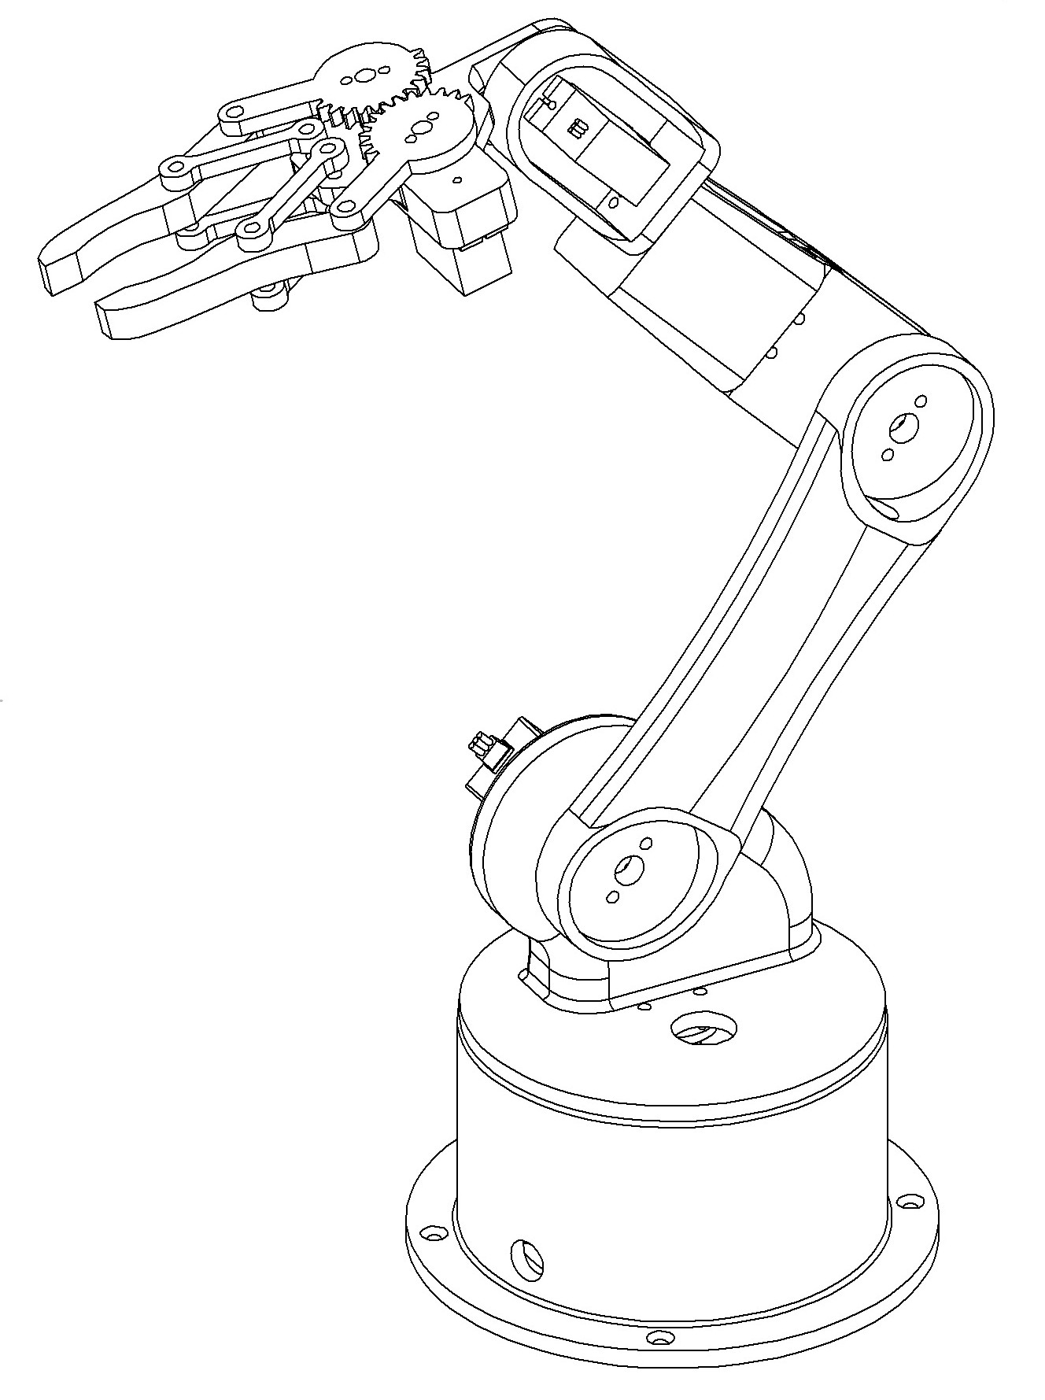
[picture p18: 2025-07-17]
Model/Images/Plain.JPG

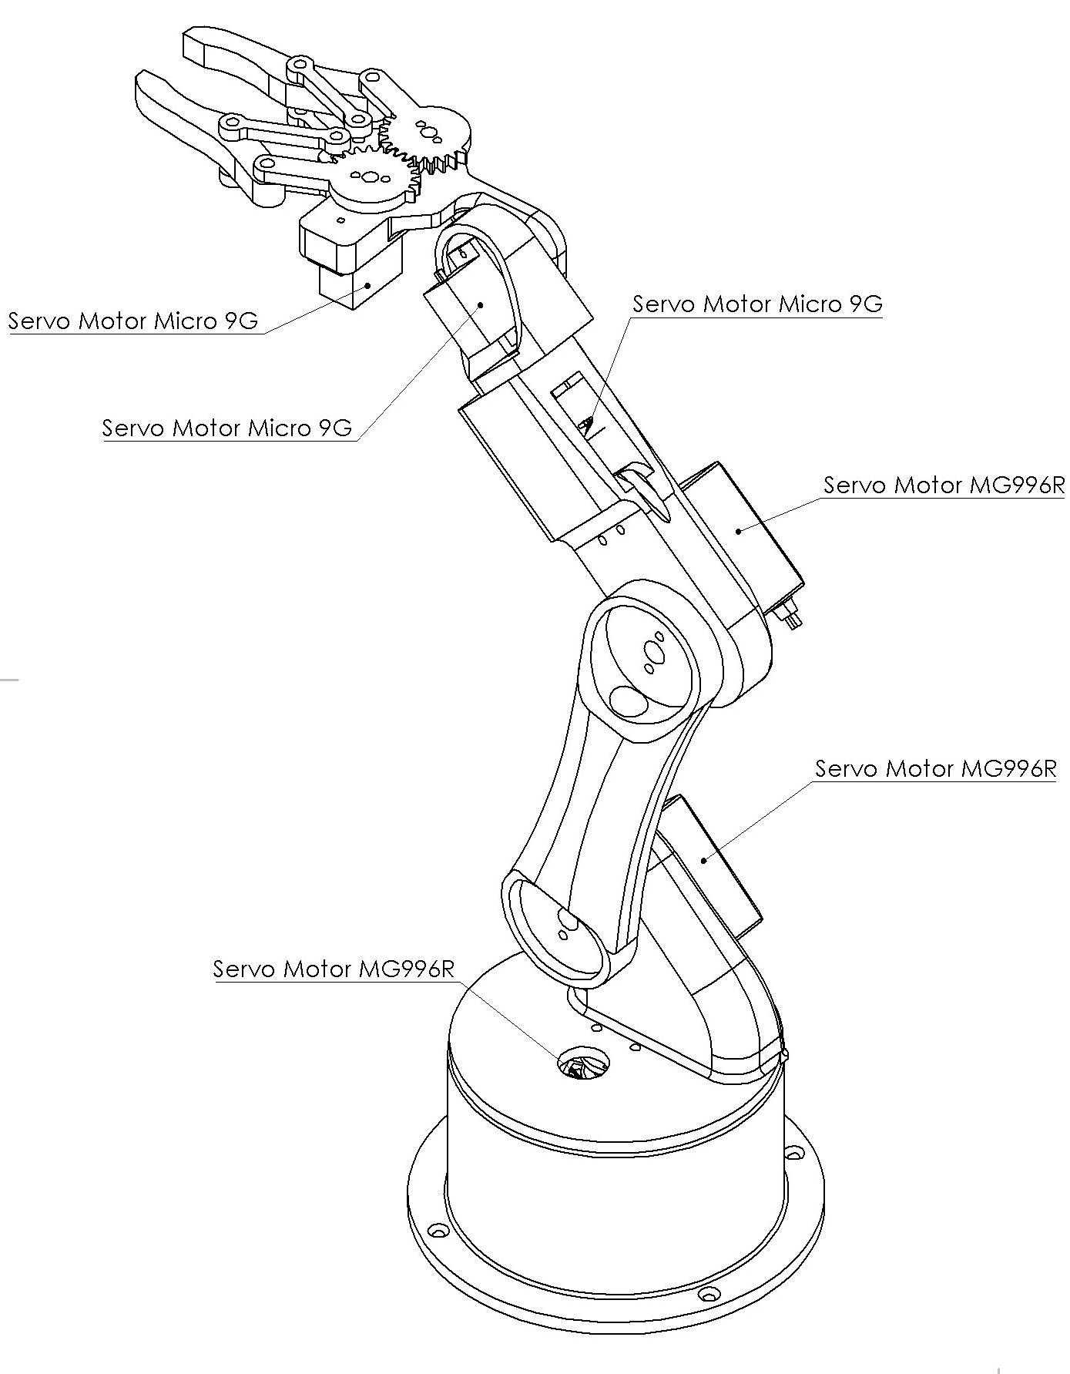
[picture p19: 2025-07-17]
Model/Images/Motors.JPG

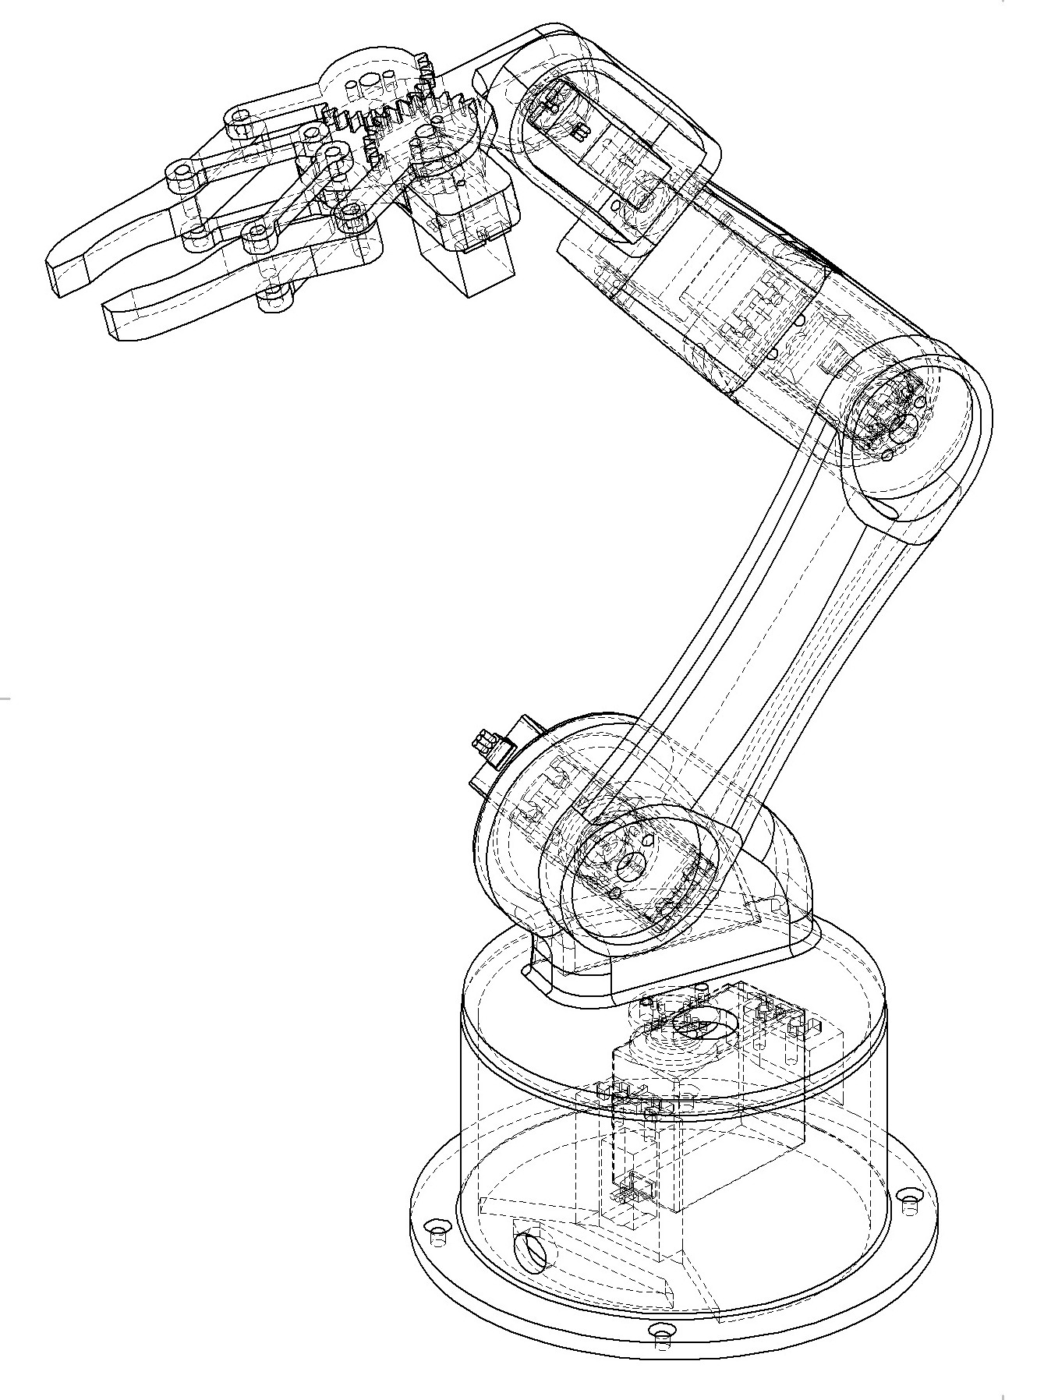
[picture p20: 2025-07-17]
Model/Images/X-Ray.JPG

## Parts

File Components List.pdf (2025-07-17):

## List of components required for each student

Name of Component | Number
STM32F103C8T6 - STM32 Development Board original IC (The Blue Pill)

IMU MPU6050 “3-axis Acceleration Gyroscope Module”

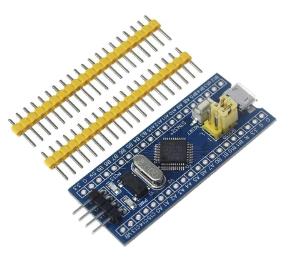
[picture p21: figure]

DC motor | 1
Coupler or Servo motor
L289 H-bridge driver module | 1
ADC 0808 | 1
Bread board | 1
Resistor 330 ohm | 15
Resistor 220 ohm | 10
Resistor 1k ohm | 10
Push buttons | 5
Battery 9VDC | 2
Potentiometer 10k | 2
LEDs | 15
Voltage regulator LM 7805 | 2
Power supply (Adaptor) | 1
Cables for connections | Some
Male-Male cables | Some
ST-LINK V2 (STM8 / STM32 Programmer) (Shareable)

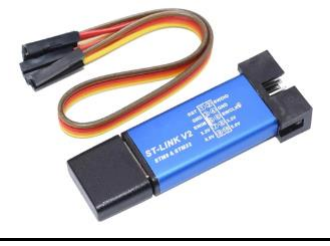
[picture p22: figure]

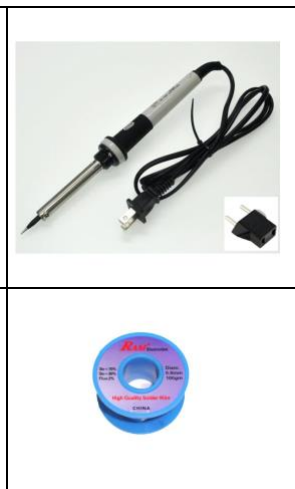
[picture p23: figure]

Soldering Iron (Shareable)

Tin for soldering (Shareable)

Sandpaper (Shareable)

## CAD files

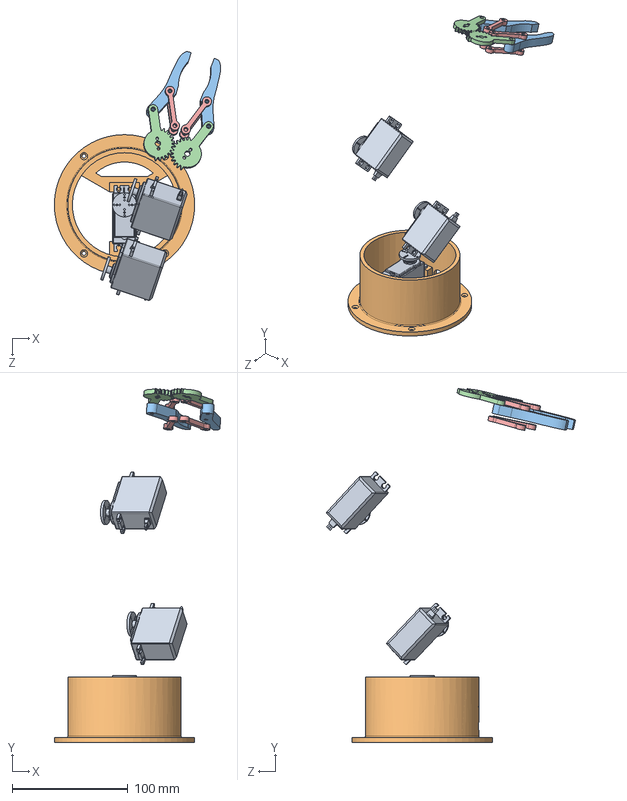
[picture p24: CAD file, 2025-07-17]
Model/Prototype Assembly.SLDASM
143.7 x 305.8 x 215.2 mm
Gripper Link x 4
Gear 1&2 x 2
Gripper x 2
Robotic Arm Base
Servo Motor MG996R x 3

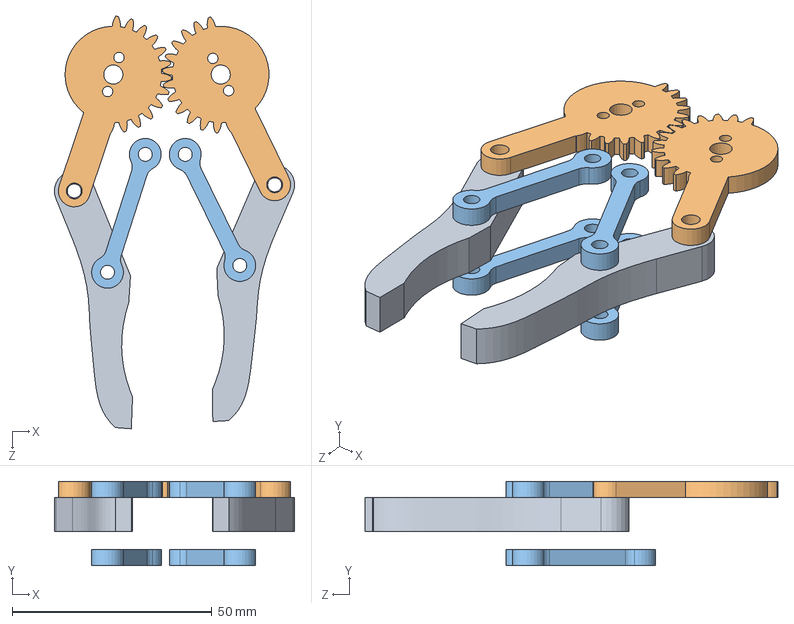
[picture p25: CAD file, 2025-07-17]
Model/Gripper Assembly.SLDASM
60.1 x 21.1 x 103.4 mm
Gripper Link x 4
Gear 1&2 x 2
Gripper x 2

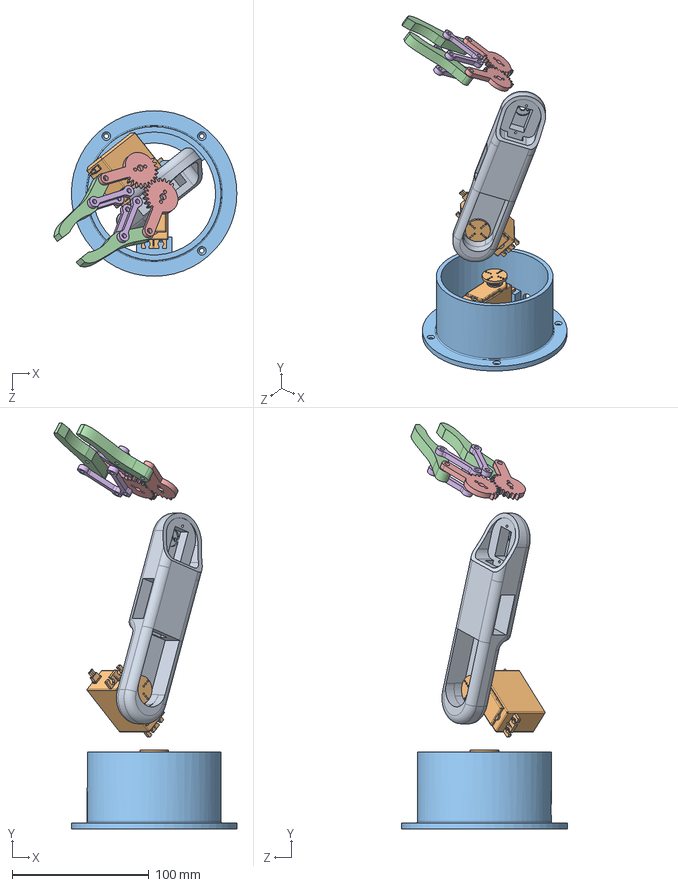
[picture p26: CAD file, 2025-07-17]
Model/Final Assembly.SLDASM
133.9 x 297.4 x 121.2 mm
Gripper Link x 4
Gear 1&2 x 2
Gripper x 2
Robotic Arm Base
Servo Motor MG996R x 2
Arm

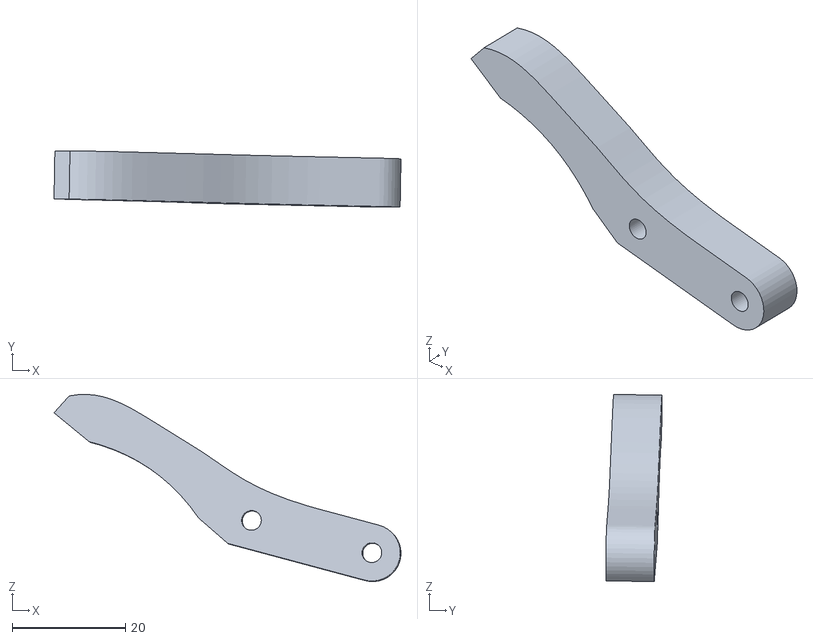
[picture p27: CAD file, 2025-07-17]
Model/STL Files/Gripper 2.STL
61.2 x 9.96 x 33.0

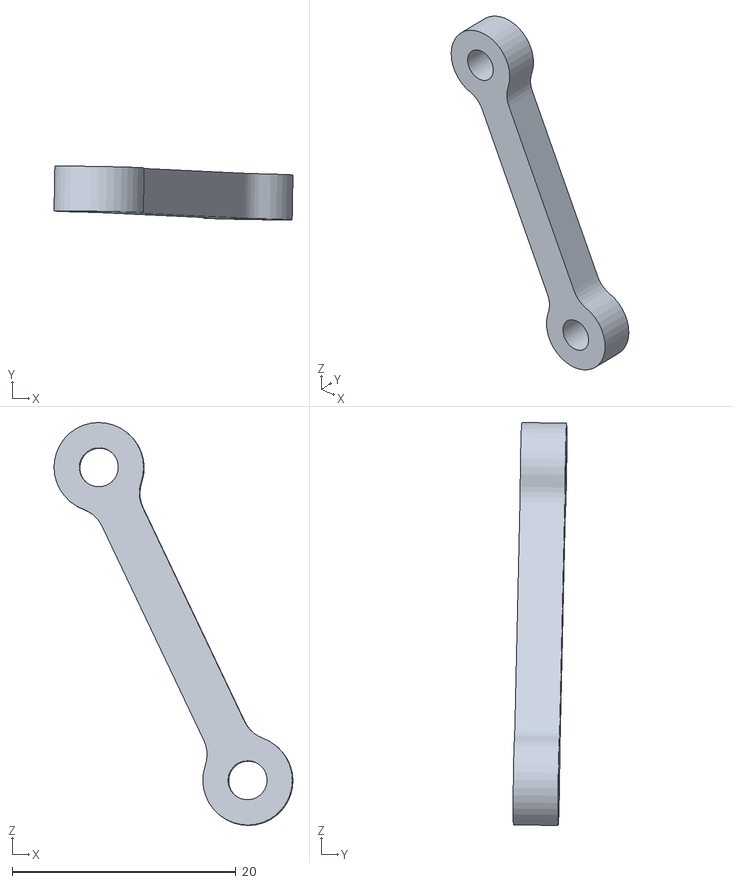
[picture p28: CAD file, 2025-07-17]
Model/STL Files/Gripper Link 1.STL
21.4 x 4.81 x 36.0

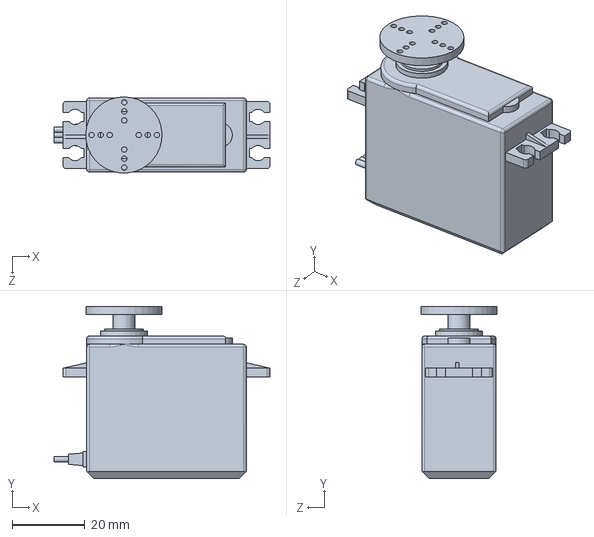
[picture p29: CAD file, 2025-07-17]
Model/Servo Motor MG996R.SLDPRT
59.5 x 47.4 x 21.0 mm

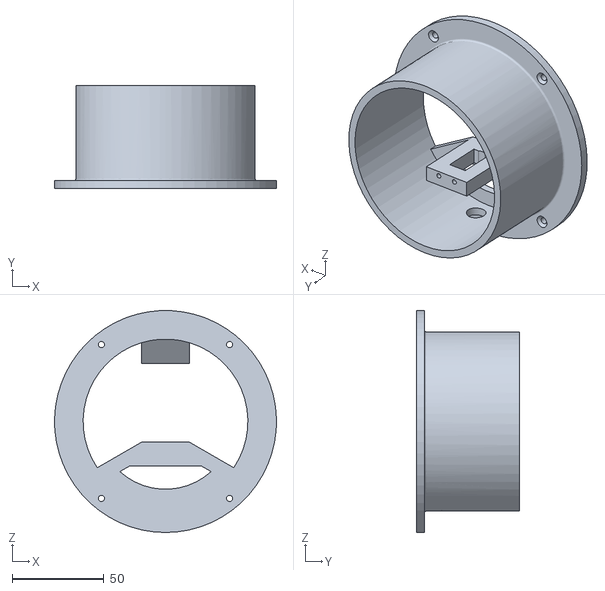
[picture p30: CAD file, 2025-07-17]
Model/STL Files/Base.STL
121.2 x 56.5 x 121.3

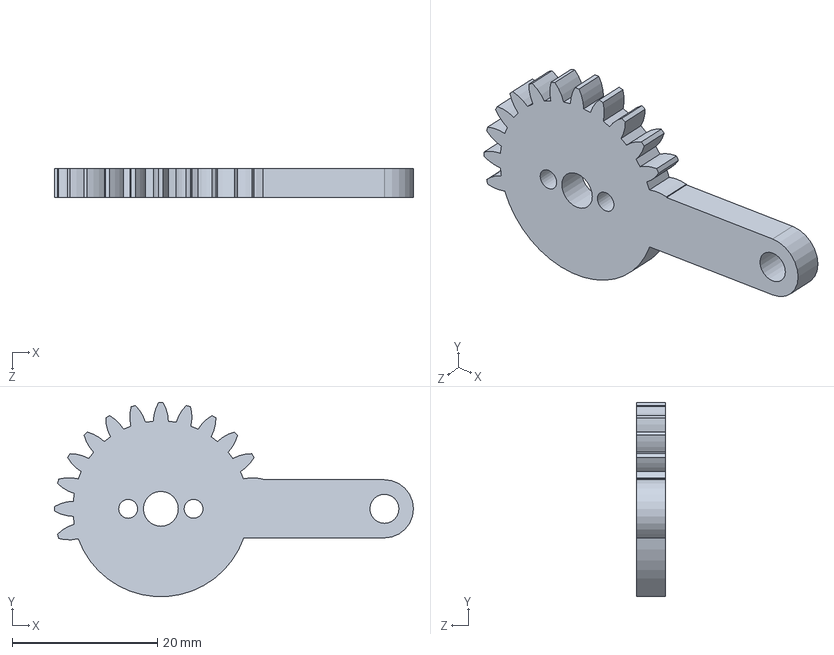
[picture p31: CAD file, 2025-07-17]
Model/Gear 1&2.SLDPRT
49.4 x 26.7 x 4.00 mm

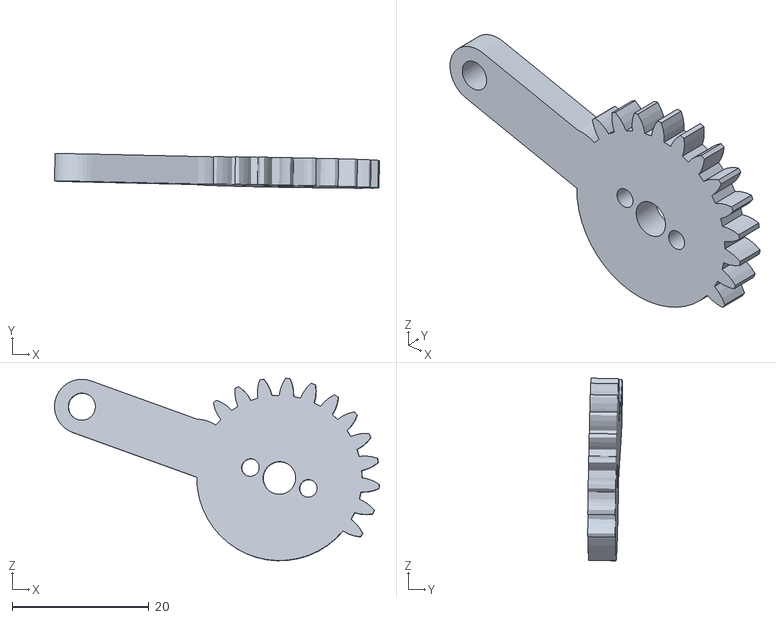
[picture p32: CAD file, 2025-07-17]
Model/STL Files/Gear 2.STL
47.6 x 5.09 x 26.7

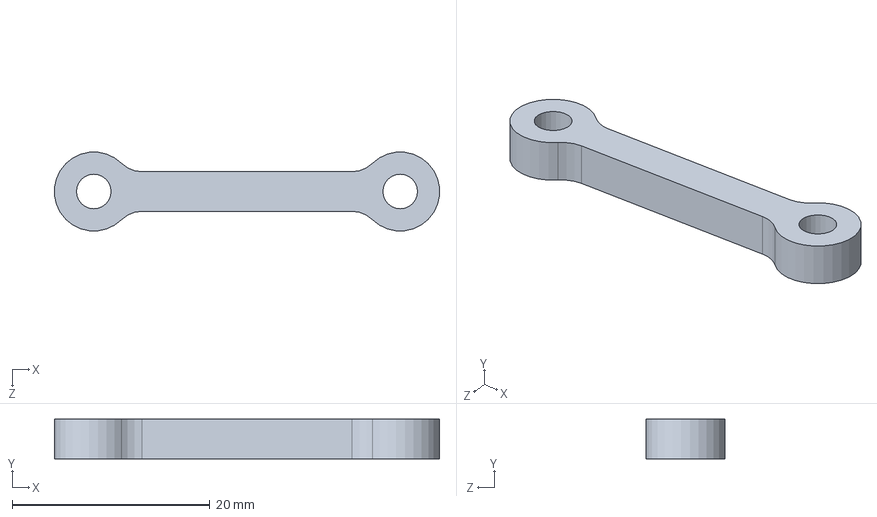
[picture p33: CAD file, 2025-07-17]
Model/Gripper Link.SLDPRT
39.0 x 4.00 x 7.96 mm

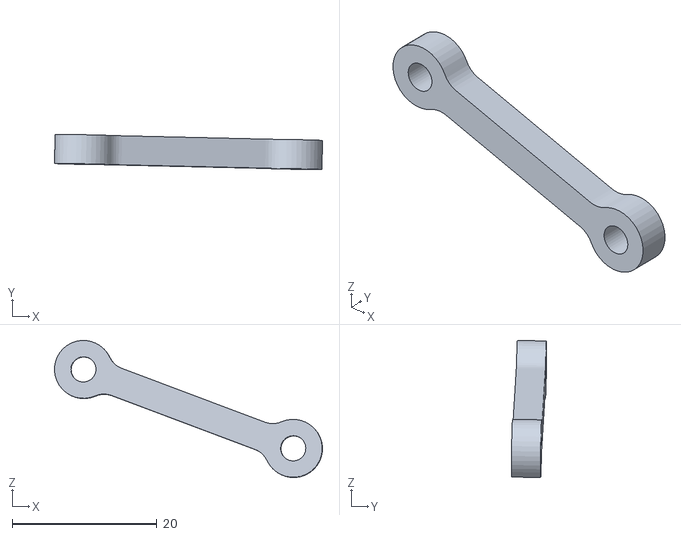
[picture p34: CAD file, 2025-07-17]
Model/STL Files/Gripper Link 3.STL
37.1 x 4.85 x 18.9

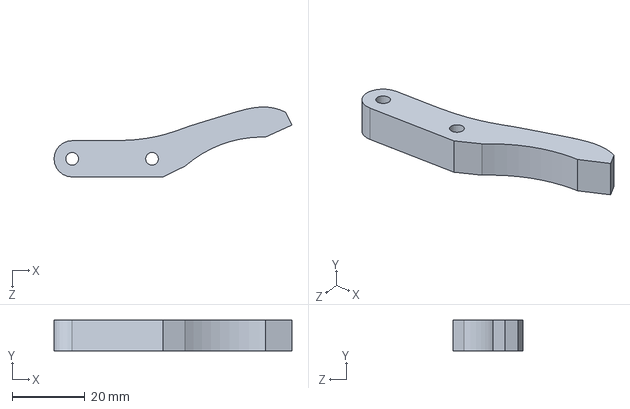
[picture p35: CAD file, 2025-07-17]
Model/Gripper.SLDPRT
65.6 x 8.50 x 19.3 mm

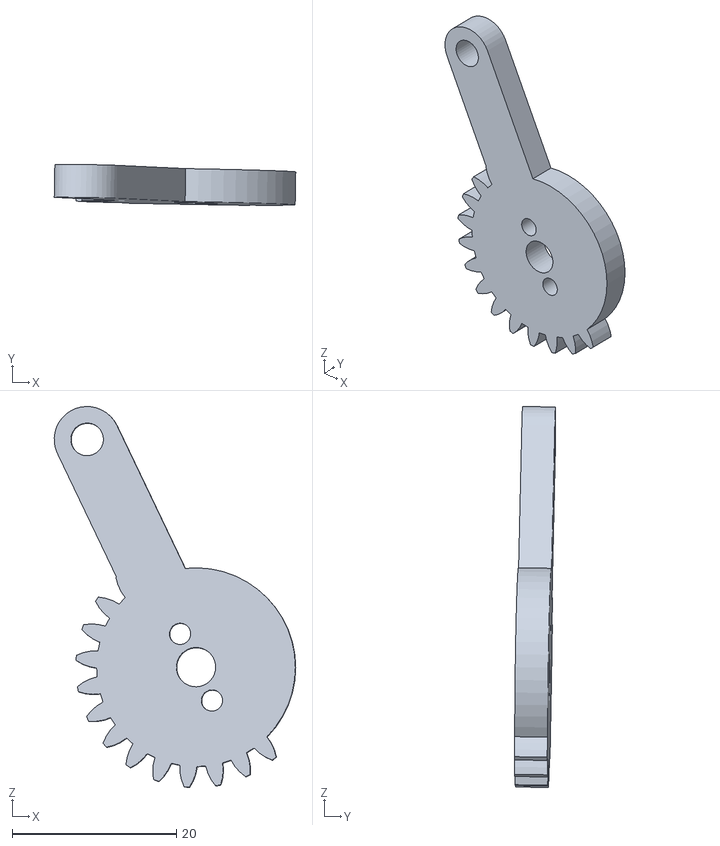
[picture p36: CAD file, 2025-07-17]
Model/STL Files/Gear 1.STL
29.4 x 5.05 x 46.4

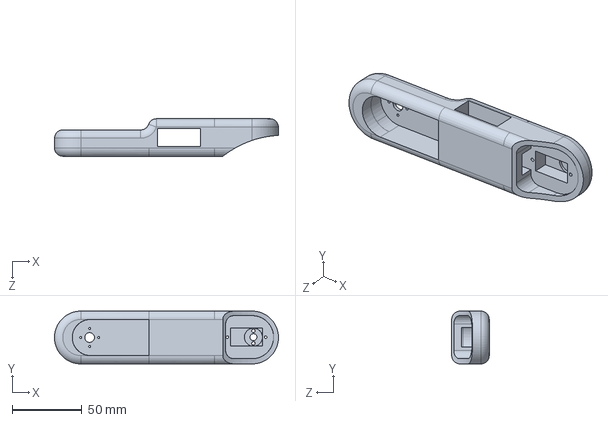
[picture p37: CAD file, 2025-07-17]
Model/Arm.SLDPRT
161.0 x 38.0 x 27.0 mm

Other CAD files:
Model/STL Files/Gripper Link 4.STL
Model/Robotic Arm Base.SLDPRT
Model/STL Files/Gripper Link 2.STL
Model/STL Files/Gripper 1.STL
Model/Arm 1.SLDPRT
Model/Arm 2.SLDPRT
Model/Arm 3.SLDPRT
Model/Gripper Base.SLDPRT
Model/Robotic Arm.SLDDRW
Model/STL Files/Arm.STL
Model/STL Files/Gripper Base.STL
Model/STL Files/Waist.STL
Model/Servo Motor Micro 9g.SLDPRT
Model/Waist.SLDPRT
